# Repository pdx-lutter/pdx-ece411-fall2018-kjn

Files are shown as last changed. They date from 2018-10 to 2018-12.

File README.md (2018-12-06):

# Portland State University

## ECE 411 Practicum Project - Group 16

### Precision Temperature Control Unit

### Group Members

* Nathan Lutterman  
* Kimball Davis  
* Jason Houlihan  

### What is it?

Our group is designing and building a temperature control unit.  In a nutshell, the device reads some ambient temperature from a temperature sensor.  If the temperature being read is outside of some bound, above or blow, the device activates and utilizes a fan or a lamp (as a heater) respectively.

It's intended to be a small, portable temperature control unit.  The user interface consists of several 7-segment digital displays which are used as feedback for the user while inputting values for thresholds, as well as displaying the temperature being read.

### What's in it?

The device mostly charge is an AT89S52 8-bit microcontroller.  It'll be driving the 7-segment displays, reading the data from the temperature sensor, and triggering the relays for the fan and lamp.

---

### Important Documents

[Preliminary EAGLE PCB Design Schematic](docs/schematics/preliminary.sch)

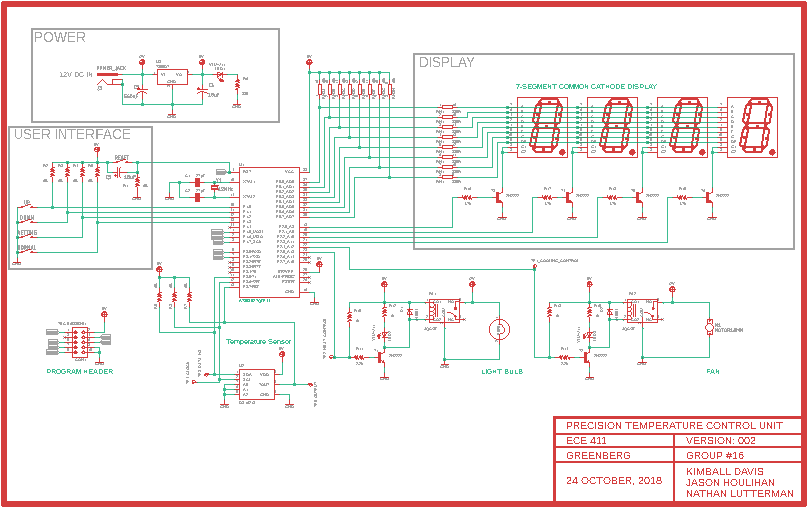
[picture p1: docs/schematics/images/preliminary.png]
Preliminary Schematic Thumbnail


### Licenses
SDCC suite is a collection of several components derived from different sources with different licenses.  

All project shared libraries used and provided by sdcc are under the GPL with the following exception:

>   As a special exception, if you link this library with other files,
>   some of which are compiled with SDCC, to produce an executable,
>   this library does not by itself cause the resulting executable to
>   be covered by the GNU General Public License. This exception does
>   not however invalidate any other reasons why the executable file
>   might be covered by the GNU General Public License.

The following is from the sdcc manual (found [here](http://sdcc.sourceforge.net/doc/sdccman.pdf)):

> – sdcc compiler:
> sdcc compiler is licensed under the GPLv2.
> The code or object files generated by SDCC suite are not licensed, so they can be used in FLOSS or
> proprietary (closed source) applications.
> 
> – dcpp preprocessor:
> derived from GCC cpp preprocessor http://gcc.gnu.org/; GPLv3 license
> 
> – sdas assemblers and sdld linker:
> derived from ASXXXX http://shop-pdp.kent.edu/ashtml/asxxxx.htm;
> license
> 
> – SDCC run-time libraries:
> The great majority of SDCC run-time libraries are licensed under the GPLv2+LE which allows linking
> of SDCC run-time libraries with proprietary (closed source) applications.
> Exception are pic device libraries and header files which are derived from Microchip header (.inc) and
> linker script (.lkr) files. Microchip requires that "The header files should state that they are only to
> be used with authentic Microchip devices" which makes them incompatible with the GPL. Pic device
> libraries and header files are located at non-free/lib and non-free/include directories respectively. SDCC
> should be run with the --use-non-free command line option in order to include non-free header files and
> libraries.
> 
> – sdbinutils utilities (sdar, sdranlib, sdnm, sdobjcopy):
> derived from GNU Binutils http://www.gnu.org/software/binutils/; GPLv3 license
> 
> – sdcclib librarian:
> GPLv2 license
> 
> – ucsim simulators:
> GPLv2 license
> 
> – sdcdb debugger:
> GPLv2 license
> 
> – gcc-test regression tests:
> derived from gcc-testsuite; no license explicitely specified, but since it is a part of GCC is probably
> GPLv3 licensed
> 
> – packihx:
> public domain
> 
> – makebin:
> zlib/libpng License
> 
> • libraries:
> – dbuf library:
> zlib/libpng License
> – Boost C++ libraries:
> http://www.boost.org/; Boost Software License 1.0 (BSL-1.0)
> Links to licenses:
> • GPLv2 license: http://www.gnu.org/licenses/old-licenses/gpl-2.0.html
> • LGPLv2.1 license: http://www.gnu.org/licenses/old-licenses/lgpl-2.1.html
> • GPLv3 license: http://www.gnu.org/licenses/gpl.html
> • zlib/libpng License: http://www.opensource.org/licenses/Zlib
> • Boost Software License 1.0 (BSL-1.0): http://www.opensource.org/licenses/BSL-1.0

The sdcc math.h and stdbool.h headers and libraries were used in the firmware of this project.

#### sdcc math.h License

   math.h: Floating point math function declarations

   Copyright (C) 2001, Jesus Calvino-Fraga, jesusc@ieee.org

   This library is free software; you can redistribute it and/or modify it
   under the terms of the GNU General Public License as published by the
   Free Software Foundation; either version 2, or (at your option) any
   later version.

   This library is distributed in the hope that it will be useful,
   but WITHOUT ANY WARRANTY; without even the implied warranty of
   MERCHANTABILITY or FITNESS FOR A PARTICULAR PURPOSE. See the
   GNU General Public License for more details.

   You should have received a copy of the GNU General Public License
   along with this library; see the file COPYING. If not, write to the
   Free Software Foundation, 51 Franklin Street, Fifth Floor, Boston,
   MA 02110-1301, USA.

   As a special exception, if you link this library with other files,
   some of which are compiled with SDCC, to produce an executable,
   this library does not by itself cause the resulting executable to
   be covered by the GNU General Public License. This exception does
   not however invalidate any other reasons why the executable file
   might be covered by the GNU General Public License.

#### sdcc stdbool.h

   stdbool.h - ANSI functions forward declarations

   Copyright (C) 2004, Maarten Brock, sourceforge.brock@dse.nl

   This library is free software; you can redistribute it and/or modify it
   under the terms of the GNU General Public License as published by the
   Free Software Foundation; either version 2, or (at your option) any
   later version.

   This library is distributed in the hope that it will be useful,
   but WITHOUT ANY WARRANTY; without even the implied warranty of
   MERCHANTABILITY or FITNESS FOR A PARTICULAR PURPOSE. See the
   GNU General Public License for more details.

   You should have received a copy of the GNU General Public License
   along with this library; see the file COPYING. If not, write to the
   Free Software Foundation, 51 Franklin Street, Fifth Floor, Boston,
   MA 02110-1301, USA.

   As a special exception, if you link this library with other files,
   some of which are compiled with SDCC, to produce an executable,
   this library does not by itself cause the resulting executable to
   be covered by the GNU General Public License. This exception does
   not however invalidate any other reasons why the executable file
   might be covered by the GNU General Public License.

#### 8051.h 

   8051.h: Register Declarations for the Intel 8051 Processor

   Copyright (C) 2000, Bela Torok / bela.torok@kssg.ch

   This library is free software; you can redistribute it and/or modify it
   under the terms of the GNU General Public License as published by the
   Free Software Foundation; either version 2, or (at your option) any
   later version.

   This library is distributed in the hope that it will be useful,
   but WITHOUT ANY WARRANTY; without even the implied warranty of
   MERCHANTABILITY or FITNESS FOR A PARTICULAR PURPOSE. See the
   GNU General Public License for more details.

   You should have received a copy of the GNU General Public License 
   along with this library; see the file COPYING. If not, write to the
   Free Software Foundation, 51 Franklin Street, Fifth Floor, Boston,
   MA 02110-1301, USA.

   As a special exception, if you link this library with other files,
   some of which are compiled with SDCC, to produce an executable,
   this library does not by itself cause the resulting executable to
   be covered by the GNU General Public License. This exception does
   not however invalidate any other reasons why the executable file
   might be covered by the GNU General Public License.

#### Circuit Schematic and PCB Layout Licensing

The work produced solely for this project, including the circuit diagram, PCB layout, and firmware is licensed under MIT.

Autodesk EAGLE was the CAD software used to produce both the circuit diagrams and the PCB layout design.

Autodesk EAGLE and other Autodesk trademarks may be found here: https://www.autodesk.com/company/legal-notices-trademarks/trademarks/autodesk-inc#top

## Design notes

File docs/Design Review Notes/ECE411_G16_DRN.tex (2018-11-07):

\documentclass[11pt]{article}

\usepackage[utf8]{inputenc} % Required for inputting international characters
\usepackage[T1]{fontenc} % Output font encoding for international characters

\usepackage{mathpazo} % Palatino font
\usepackage{graphicx}
\usepackage{geometry}
\usepackage{float}
\usepackage{amsmath}
\usepackage{tabu}
\usepackage{array}
\usepackage{cellspace}
\usepackage[table]{xcolor}
\usepackage{multirow}
\usepackage{multicol}
\usepackage{parskip}

\usepackage{titlesec}
\titlespacing\subsection{0pt}{1pt plus 4 pt minus 2pt}{1pt plus 4 pt minus 2pt}

\renewcommand{\baselinestretch}{1.25}
\geometry{margin=0.75 in}

\begin{document}

%----------------------------------------------------------------------------------------
%	TITLE PAGE
%----------------------------------------------------------------------------------------

\begin{titlepage} % Suppresses displaying the page number on the title page and the subsequent page counts as page 1
	\newcommand{\HRule}{\rule{\linewidth}{0.5mm}} % Defines a new command for horizontal lines, change thickness here
	
	\center % Centre everything on the page
	
	%------------------------------------------------
	%	Headings
	%------------------------------------------------
	
	\textsc{\LARGE Portland State University
}\\[.25cm] % Main heading such as the name of your university/college
	
	\textsc{\Large Department of Electrical and Computer Engineering }\\[.5cm] % Major heading such as course name
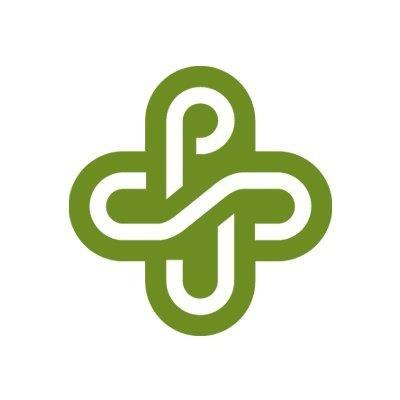
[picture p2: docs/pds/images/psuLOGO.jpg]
\\[.5cm]	
	\textsc{\LARGE ECE 411 - Industry Design Process }\\[0.75cm] % Minor heading such as course title
	
		\textsc{\Large Professor Andrew Greenberg, MS\\
Professor of Electrical \& Computer Engineering
 }\\[.75cm]
	
	%------------------------------------------------
	%	Title
	%------------------------------------------------
	
	\HRule\\[0.4cm]
	
	{\huge\bfseries Design Review Notes}\\[0.4cm] % Title of your document
	
	\HRule\\[1.5cm]
	
	%------------------------------------------------
	%	Author(s)
	%------------------------------------------------
	
%	\begin{minipage}{0.4\textwidth}
%		\begin{flushleft}
%			\large
%			\textit{By:}\\
%		 \textsc{Kimball S. Davis} % Your name
%		\end{flushleft}
%	\end{minipage}
%	~
%	\begin{minipage}{0.4\textwidth}
%		\begin{flushright}
%			\large
%			\textit{Professor of Electrical \& Computer Engineering}\\
%		 \textsc{Professor Branimir Pejcinovic, Ph.D.} % Supervisor's name
%		\end{flushright}
%	\end{minipage}
	
	% If you don't want a supervisor, uncomment the two lines below and comment the code above
	\Large{Group \#16:}\\
		 \Large\textsc{Kimball S. Davis, Jason Houlihan, \& Nathan Lutterman} % Your name
	
	%------------------------------------------------
	%	Date
	%------------------------------------------------
	
	\vfill\vfill\vfill\vfill % Position the date 3/4 down the remaining page
	
	{\large\today} % Date, change the \today to a set date if you want to be precise
	
	%------------------------------------------------
	%	Logo
	%------------------------------------------------
	
	%\vfill\vfill
	%\includegraphics[width=0.2\textwidth]{PSULOGO}\\[1cm] % Include a department/university logo - this will require the graphicx package
	 
	%----------------------------------------------------------------------------------------
	
	\vfill % Push the date up 1/4 of the remaining page
	
\end{titlepage}

%----------------------------------------------------------------------------------------
\setlength{\columnsep}{.2 in}

\setlength{\parskip}{0pt}

\section*{Schematic and Board Layout Design Review Notes}
\textbf{Team Being Reviewed:} Group 16: Kimball Davis, Jason Houlihan, Nathan Lutterman\\
\textbf{Reviewer:} Douglas Hall, Ph.D\\

\textit{NOTE: Although Professor Geenberg never directly reviewed our design, we discovered some flaws in our design while watching the reviews done in class. We included these in our review notes because we changed our design based on these observations before Dr. Hall reviewed the design.}

\section*{Schematic} 

\subsection*{Critical}

\begin{itemize}

    \item Missing bypass capacitors on +5V inputs to AT89S52. Added 100 nF bypass capacitors to design.
    \item Don't put anything on the NET layer that is not a net. We had some section labeling on the NET layer. The text was moved to the NOTES layer.
    
\end{itemize}

\subsection*{Major}

\begin{itemize}

    \item Not clear exactly what the power is coming from. Changed power supply labeling in schematic.
    \item Make sure there are adequate test points. Added test points for I2C signals for display.
    \item Not clear how much current the loads require to operate, or what the loads are. Labeled the loads on the schematic with part number, voltage, and current specifications.

\end{itemize}
		
\subsection*{Minor}

\begin{itemize}

    \item For LEDS use 500 to 1K resistors to keep them dimmer. Changed resistors in LED circuits from 330 to 1k $\Omega$
    \item When presenting a schematic for review be aware of the scale. If our schematic were projected on a screen or on a laptop with zoom capabilities it would be fine. Presented on 11x7 paper a lot of the text is hard to read.

\end{itemize}

\section*{Layout} 

\subsection*{Critical}

\begin{itemize}

    \item None
    
\end{itemize}

\subsection*{Major}

\begin{itemize}

    \item Will the voltage regulator need additional heat sinks based on the power the loads will draw?

\end{itemize}
		
\subsection*{Minor}

\begin{itemize}

    \item Consider printing top and bottom layers separately, or on transparencies that can overlap so it is easier for the reviewer to follow traces.
    \item Not clear what type of mounting hardware will be needed for connectors.

\end{itemize}

\section*{Bill of Materials} 

\begin{itemize}

    \item Power supply, fan, and light-bulb specifications are not clearly defined.
    
\end{itemize}

\end{document}

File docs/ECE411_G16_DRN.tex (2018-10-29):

\documentclass[11pt]{article}

\usepackage[utf8]{inputenc} % Required for inputting international characters
\usepackage[T1]{fontenc} % Output font encoding for international characters

\usepackage{mathpazo} % Palatino font
\usepackage{graphicx}
\usepackage{geometry}
\usepackage{float}
\usepackage{amsmath}
\usepackage{tabu}
\usepackage{array}
\usepackage{cellspace}
\usepackage[table]{xcolor}
\usepackage{multirow}
\usepackage{multicol}
\usepackage{parskip}

\usepackage{titlesec}
\titlespacing\subsection{0pt}{1pt plus 4 pt minus 2pt}{1pt plus 4 pt minus 2pt}

\renewcommand{\baselinestretch}{1.25}
\geometry{margin=0.75 in}

\begin{document}

%----------------------------------------------------------------------------------------
%	TITLE PAGE
%----------------------------------------------------------------------------------------

\begin{titlepage} % Suppresses displaying the page number on the title page and the subsequent page counts as page 1
	\newcommand{\HRule}{\rule{\linewidth}{0.5mm}} % Defines a new command for horizontal lines, change thickness here
	
	\center % Centre everything on the page
	
	%------------------------------------------------
	%	Headings
	%------------------------------------------------
	
	\textsc{\LARGE Portland State University
}\\[.25cm] % Main heading such as the name of your university/college
	
	\textsc{\Large Department of Electrical and Computer Engineering }\\[.5cm] % Major heading such as course name
\\[.5cm]
	\textsc{\LARGE ECE 411 - Industry Design Process }\\[0.75cm] % Minor heading such as course title
	
		\textsc{\Large Professor Andrew Greenberg, MS\\
Professor of Electrical \& Computer Engineering
 }\\[.75cm]
	
	%------------------------------------------------
	%	Title
	%------------------------------------------------
	
	\HRule\\[0.4cm]
	
	{\huge\bfseries Project Design Specification}\\[0.4cm] % Title of your document
	
	\HRule\\[1.5cm]
	
	%------------------------------------------------
	%	Author(s)
	%------------------------------------------------
	
%	\begin{minipage}{0.4\textwidth}
%		\begin{flushleft}
%			\large
%			\textit{By:}\\
%		 \textsc{Kimball S. Davis} % Your name
%		\end{flushleft}
%	\end{minipage}
%	~
%	\begin{minipage}{0.4\textwidth}
%		\begin{flushright}
%			\large
%			\textit{Professor of Electrical \& Computer Engineering}\\
%		 \textsc{Professor Branimir Pejcinovic, Ph.D.} % Supervisor's name
%		\end{flushright}
%	\end{minipage}
	
	% If you don't want a supervisor, uncomment the two lines below and comment the code above
	\Large{Group \#16:}\\
		 \Large\textsc{Kimball S. Davis, Jason Houlihan, \& Nathan Lutterman} % Your name
	
	%------------------------------------------------
	%	Date
	%------------------------------------------------
	
	\vfill\vfill\vfill\vfill % Position the date 3/4 down the remaining page
	
	{\large\today} % Date, change the \today to a set date if you want to be precise
	
	%------------------------------------------------
	%	Logo
	%------------------------------------------------
	
	%\vfill\vfill
	%\includegraphics[width=0.2\textwidth]{PSULOGO}\\[1cm] % Include a department/university logo - this will require the graphicx package
	 
	%----------------------------------------------------------------------------------------
	
	\vfill % Push the date up 1/4 of the remaining page
	
\end{titlepage}

%----------------------------------------------------------------------------------------
\setlength{\columnsep}{.2 in}

\setlength{\parskip}{0pt}

\section*{Executive Summary}
Everyday medical, industrial, and home applications need a precise temperature controller. Our digital temperature controller is primarily used to control the temperature of any device whose temperature keeps fluctuating and requires a constant watch. This system can be used in any organization where it is very important to maintain specific temperatures. This system is better than analogue/ thermostat systems, which have poor accuracy. Its main use is for temperature control of an incubator where maintaining a precise temperature is very important.\\

The digital temperature controller provides the temperature information on a LCD display, and when the temperature exceeds the set point, the load (heater) switches off. For the purpose of our practicum project, a lamp will be used as a load for demonstration purpose. If time permits we would also add a fan to cool the device when the temperature exceeds the set limit. Therefore the system keep switching the lamp, and fan, on and off which automatically controls the temperature of the system.\\

The digital temperature controller uses a microcontroller from the 8051 family (AT89S52), which is the bulk of the application. The display unit consists of four seven segment display pins which are interfaced to the microcontroller. The digital temperature sensor (DS1621) is interfaced to the microcontroller for sensing the temperature conditions. The system also provides four push buttons switches for adjusting, and setting the temperature. The microcontroller then polls the temperature information through a digital temperature sensor and displays the seven segment display units. When the corresponding temperature exceeds the set point, the lamp/fan automatically switches off/on.\\

The following are some examples of digital temperature controller using a microcontroller:
\begin{itemize}
    \item Outdoor use involving potential chemical contamination or electrical interference.
    \item Outdoor use involving potential chemical contamination or electrical interference.
    \item Medical equipment, amusement machines, vehicles, safety equipment, and installations subject to separate industry or government regulations.
    \item Systems, machines, and equipment that could present a risk to life or property.
    \item HVAC control for industrial and residential applications.
\end{itemize}

\pagebreak

\section*{Brief Market Analysis} 

While there are many uses for precision programmable temperature control units, home heating and cooling is a place where there is an available market, and a need for better more efficient thermostats. In a survey from the U.S. Energy Information Agency (EIA) it was found that while over 87$\%$of homes were equipped with HVAC, only roughly 52$\%$ of them had programmable thermostats. There is plenty of competition in the market from industry giants such as General Electric, Honeywell, and Emerson who currently have many similar products available some even offering entire smart home systems.\\

Where there is room for growth in the market is in ease of use, customization, and peripherals. A few things that would make our product stand out from the rest would be: LCD touchscreens, data logging for predictive thermostat control,and RFID implementation for personalized thermostat settings from room to room.\\

Ideally there would be several models with the same basic TCU as the engine. The price would depend on if it was the base model or the more advanced models with more functions/peripherals. Similar products on the market range from \$60 to \$100 for a basic programmable thermostat, and up to \$250 for the more advanced programmable models.

\section*{Requirements}
\subsection*{Must}
\begin{itemize}
    \item Accurately detect temperature 
    \item Accurately report temperature through a display
    \item Have a programmable temperature setting
    \item Switch between heating and cooling modes when temperature threshold is exceeded 
    \item Be easy to use
    \item Use an AT89S52 microcontroller
    \item Use > 25\% SMT components
    \item Have the processor on the PCB 
    \item Have in circuit Programming capabilities
    \item Use a two or more layer PCB, with solder mask and at least a top-side silk screen
    \item Area between 9-900 $cm^2$, and a linear dimension between 2-30 cm

\end{itemize}

\subsection*{Should}

\begin{itemize}

    \item Be as small as possible
    \item Have an enclosure

\end{itemize}
		
\subsection*{May}

\begin{itemize}

    \item Have data logging capabilities
    \item Have an LCD screen
    \item Include RFID programming

\end{itemize}

\section*{System Architecture}
The level 1 block diagram for our proposed design can be seen below.
	
	\begin{figure}[H]
	\centering
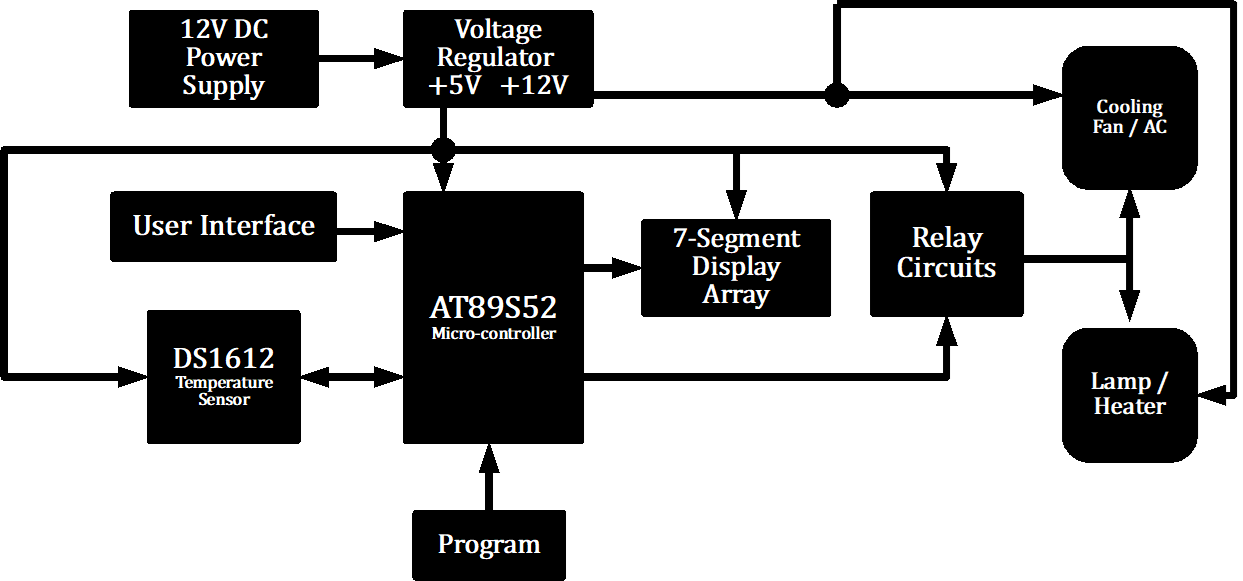
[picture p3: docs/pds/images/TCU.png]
	
		\caption{\textit{Block diagram of digital temperature controller.}}
	\end{figure}

\section*{Design Specifications}

\subsection*{Sensors}
\begin{itemize}
	\setlength\itemsep{-2px}
    \item Digital Temperature Sensor(DS1621)
    \item Push Buttons.

\end{itemize}

\subsection*{Actuators}
\begin{itemize}
	\setlength\itemsep{-2px}
    \item 7 Segment display pins
    \item Lamp and fan
    \item LEDs
\end{itemize}

\subsection*{Controller}
\begin{itemize}
	\setlength\itemsep{-2px}
    \item Microcontroller (AT89S52)
\end{itemize}

\subsection*{Additional}
\begin{itemize}
	\setlength\itemsep{-2px}
    \item Voltage regulator (LM7805C)
    \item Transistors (2N2222) 
    \item 5V Relays (JQC-3F)
    \item Resistors/Capacitors

\end{itemize}
	
\end{document}

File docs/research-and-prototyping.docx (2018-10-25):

Research and Prototyping

10/16/2018

I ordered the following USB ISP for programming the AT89S52. It is a requirement that we be able to program the MC in circuit and not on a daughter board. Read the specs in the link.

https://www.amazon.com/gp/product/B00AX4WQ00/ref=oh_aui_detailpage_o00_s00?ie=UTF8&psc=1

From the description they had the following layout for programming the MC for a different chip in a TQFP 32 pin out shown below.

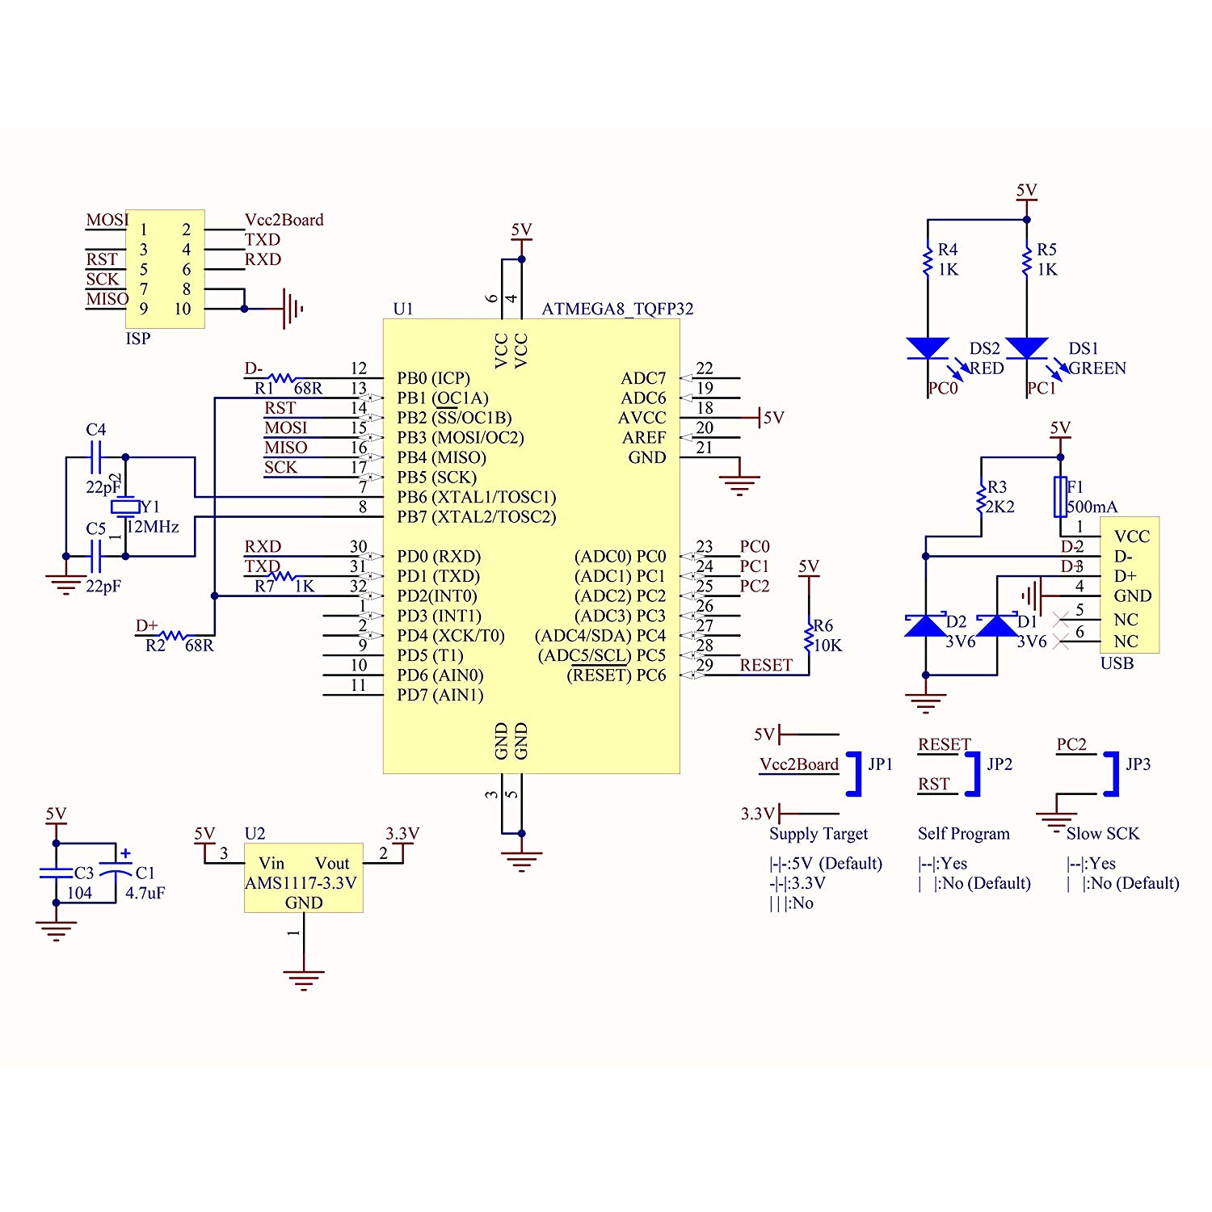
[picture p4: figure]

I translated the schematic for a basic pin out from the 10-pin connector for an AT89S52 in EAGLE shown below.

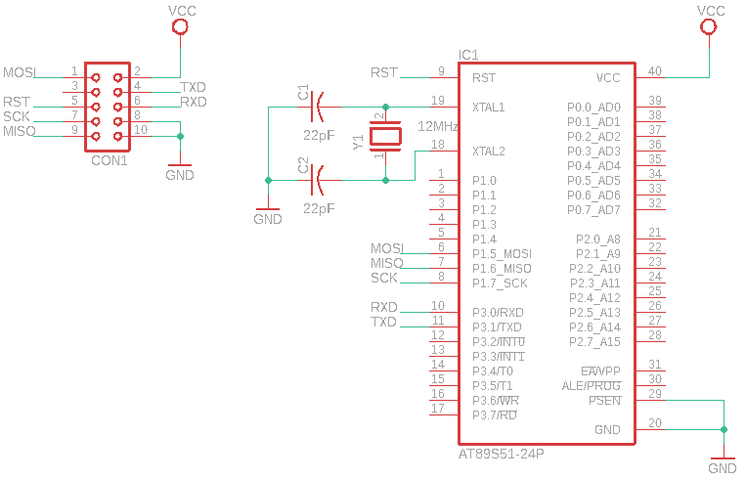
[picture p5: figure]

The only microcontroller I’ve ever used is the Beagle bone black from 371. I’ll need your feedback on what else this circuit needs or is missing for basic programming. I figure this is a good place to start, so we can get programming, and test functionality.

I’ve also requested free samples from ATMEL of AT89S52 in a DIL40 pin package. I have two coming that should be here in a week to a week and a half. We may want to order some that will get here faster.

The parts list from Jason’s link is below as well as a block diagram of the circuit.

- AT89S52 (8051 Microcontroller) – Buy AT89S52 Online (http://nevonexpress.com/AT89S52-8-Bit-Microcontroller-DIP-Mount-8051-Family.php)
- 7 Segment Display – Buy 7 Segment DIsplay Online (http://nevonexpress.com/7-Segment-Display-CA.php)
- DC Cooling Fan – Buy DC Fan Online (http://nevonexpress.com/12v-Brushless-DC-Cooling-Exhaust-Fan.php)
- LM35 Temperature Sensor – Buy LM35 Sensor Online (http://nevonexpress.com/LM35-Temperature-Sensor-For-Arduino-Ras-Pi-Microcontroller.php)
- Relay – Buy Relays Online (http://nevonexpress.com/Buy-Relays-Online.php)
- Relay Driver IC – Buy IC’s Online (https://nevonexpress.com/Buy-IC-and-Controllers-Online.php)
- Vtg Regulator IC – Buy IC’s Online (https://nevonexpress.com/Buy-IC-and-Controllers-Online.php)
- IC Socket – Buy IC Sockets Online (https://nevonexpress.com/Buy-IC-Sockets-Online.php)
- Resistors – Buy Resistors Online (https://nevonexpress.com/Buy-Resistors-Online.php)
- Capacitors – Buy Capacitors Online (https://nevonexpress.com/Buy-Capacitors-Online.php)
- Transistors – Buy Transistors Online (https://nevonexpress.com/Buy-Transistors-Online.php)
- Cables & Connectors – Buy Cables & Connectors Online (http://nevonexpress.com/Cables-&-Connectors.php)
- Diodes – Buy Diodes Online (https://nevonexpress.com/Buy-Diodes-Online.php)
- PCB – Buy PCB & Breadboards Online (https://nevonexpress.com/Buy-PCB-Breadboards-Online.php)
- LED’s – Buy LED Online (https://nevonexpress.com/Buy-LED-Displays-Online.php)
- Transformer/Adapter – Buy Transformers & Adapters Online (http://nevonexpress.com/Transformers.php)
- Push Button – Buy Buttons & Switches Online (https://nevonexpress.com/Buy-Electronics-Buttons-Switches-Online.php)
- Lamp

Software Specifications

- Keil µVision IDE
- MC Programming Language: Embedded C

Block Diagram

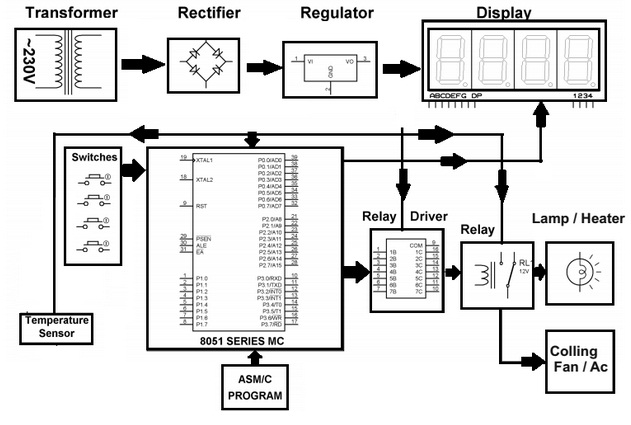
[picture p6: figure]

I think it will be a lot cheaper to order all of the parts individually, they want $105 for the kit which includes a pcb that we won’t need.

My thoughts on what we could do different for our project:

- Use a different/ more advanced temperature sensor
- Data logging
- 4 7-segment displays instead of 3
- We could have different loads to switch besides a dc fan and a light bulb
- We could build an actual enclosure to show proof of concept
- RFID tags that automatically set the temperature for a person when they walk into a room. (stolen from the lock box idea)

Some of these may be too much added work, I’ll need your feedback as to what you guys think is possible in the given amount of time.

Requirements/Specification Ideas:

- Parts list
  - Loads: Fan/lightbulb or Other
  - Temperature Sensor
  - RFID?
  - >25% SMT components
  - Correct 10-pin ribbon connector
- Temperature Range
- Sensitivity
- Power consumption
- Enclosure?
- Display
- Size
- Operation

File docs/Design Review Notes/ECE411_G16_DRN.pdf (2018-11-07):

### PORTLAND STATE UNIVERSITY

DEPARTMENT OF ELECTRICAL AND COMPUTER ENGINEERING


### ECE 411 - INDUSTRY DESIGN PROCESS

PROFESSOR ANDREW GREENBERG, MS PROFESSOR OF ELECTRICAL & COMPUTER ENGINEERING

# Design Review Notes

## Group #16:

KIMBALL S. DAVIS, JASON HOULIHAN, & NATHAN LUTTERMAN

November 7, 2018

### Schematic and Board Layout Design Review Notes

Team Being Reviewed: Group 16: Kimball Davis, Jason Houlihan, Nathan Lutterman
Reviewer: Douglas Hall, Ph.D

NOTE: Although Professor Geenberg never directly reviewed our design, we discovered some flaws in our design while watching the reviews done in class. We included these in our review notes because we changed our design based on these observations before Dr. Hall reviewed the design.

### Schematic

Critical
- Missing bypass capacitors on +5V inputs to AT89S52. Added 100 nF bypass capacitors to design.
- Don’t put anything on the NET layer that is not a net. We had some section labeling on the NET layer. The text was moved to the NOTES layer.
Major
- Not clear exactly what the power is coming from. Changed power supply labeling in schematic.
- Make sure there are adequate test points. Added test points for I2C signals for display.
- Not clear how much current the loads require to operate, or what the loads are. Labeled the loads on the schematic with part number, voltage, and current specifications.
Minor
- For LEDS use 500 to 1K resistors to keep them dimmer. Changed resistors in LED circuits from 330 to 1k Ω
- When presenting a schematic for review be aware of the scale. If our schematic were projected on a screen or on a laptop with zoom capabilities it would be fine. Presented on 11x7 paper a lot of the text is hard to read.

### Layout

Critical
- None
Major
- Will the voltage regulator need additional heat sinks based on the power the loads will draw? Minor
- Consider printing top and bottom layers separately, or on transparencies that can overlap so it is easier for the reviewer to follow traces.
- Not clear what type of mounting hardware will be needed for connectors.

### Bill of Materials

- Power supply, fan, and light-bulb specifications are not clearly defined.

1

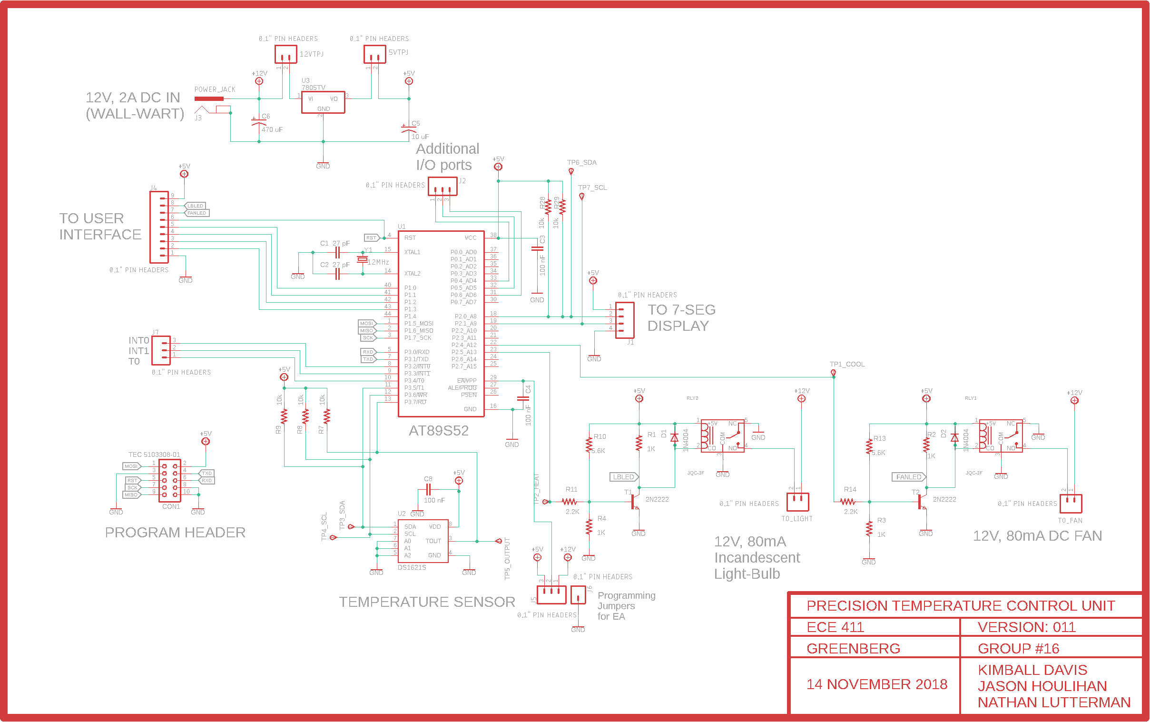
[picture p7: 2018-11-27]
docs/Schematics and Board designs/images/ECE411_G16_V11.png

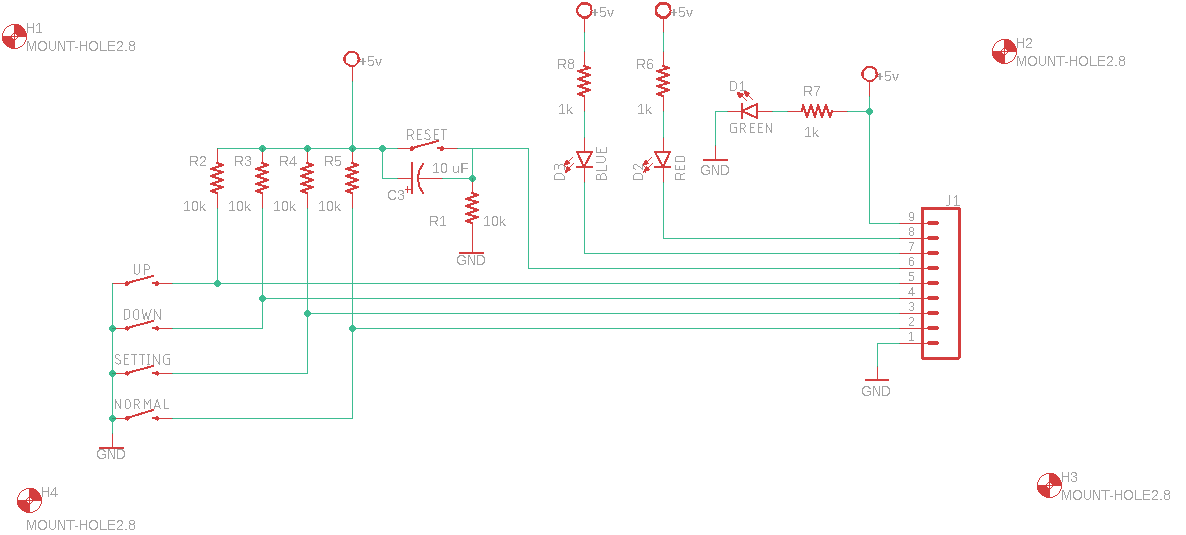
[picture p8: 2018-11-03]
docs/Schematics and Board designs/images/ECE411_G16_UIV1.png

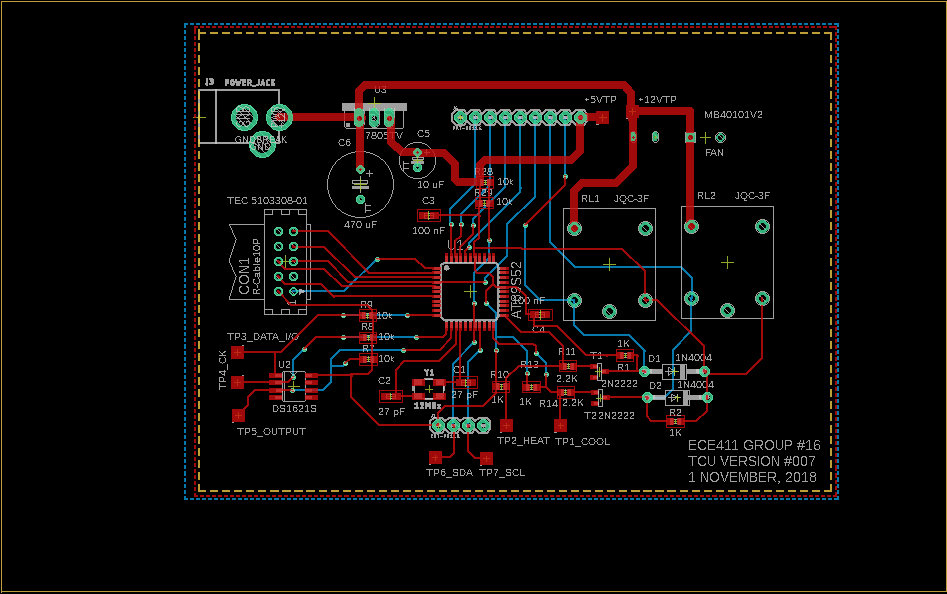
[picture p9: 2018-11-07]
docs/Schematics and Board designs/images/ECE411_G16_V7_BRD.png

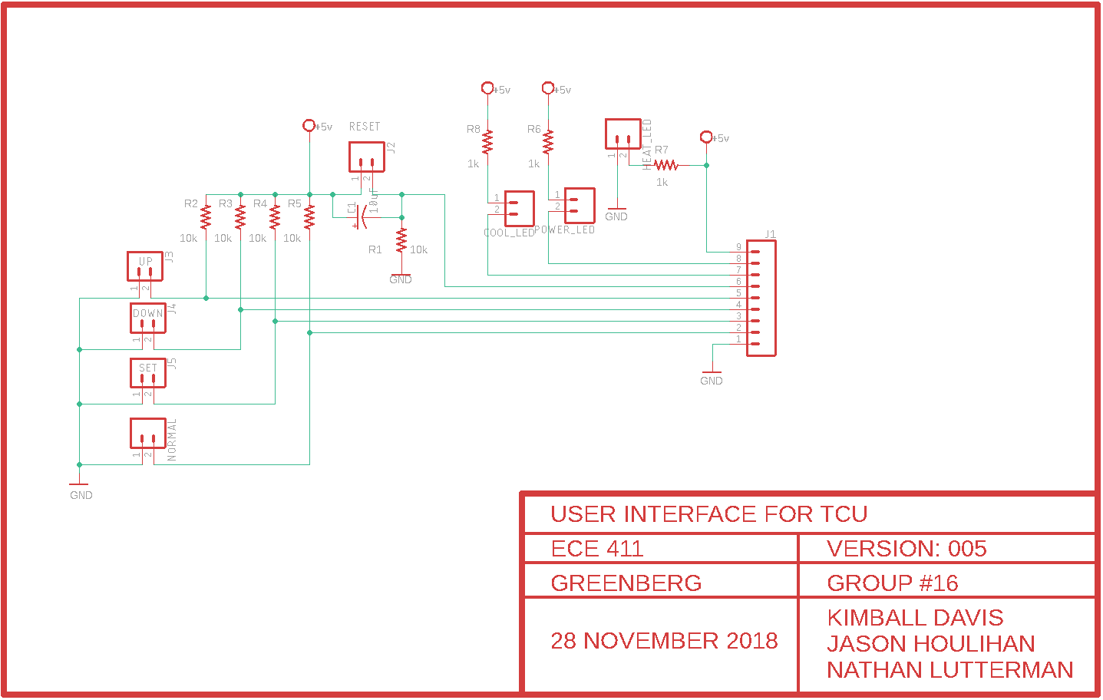
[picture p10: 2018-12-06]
docs/Schematics and Board designs/images/ECE411_G16_UIV5.png

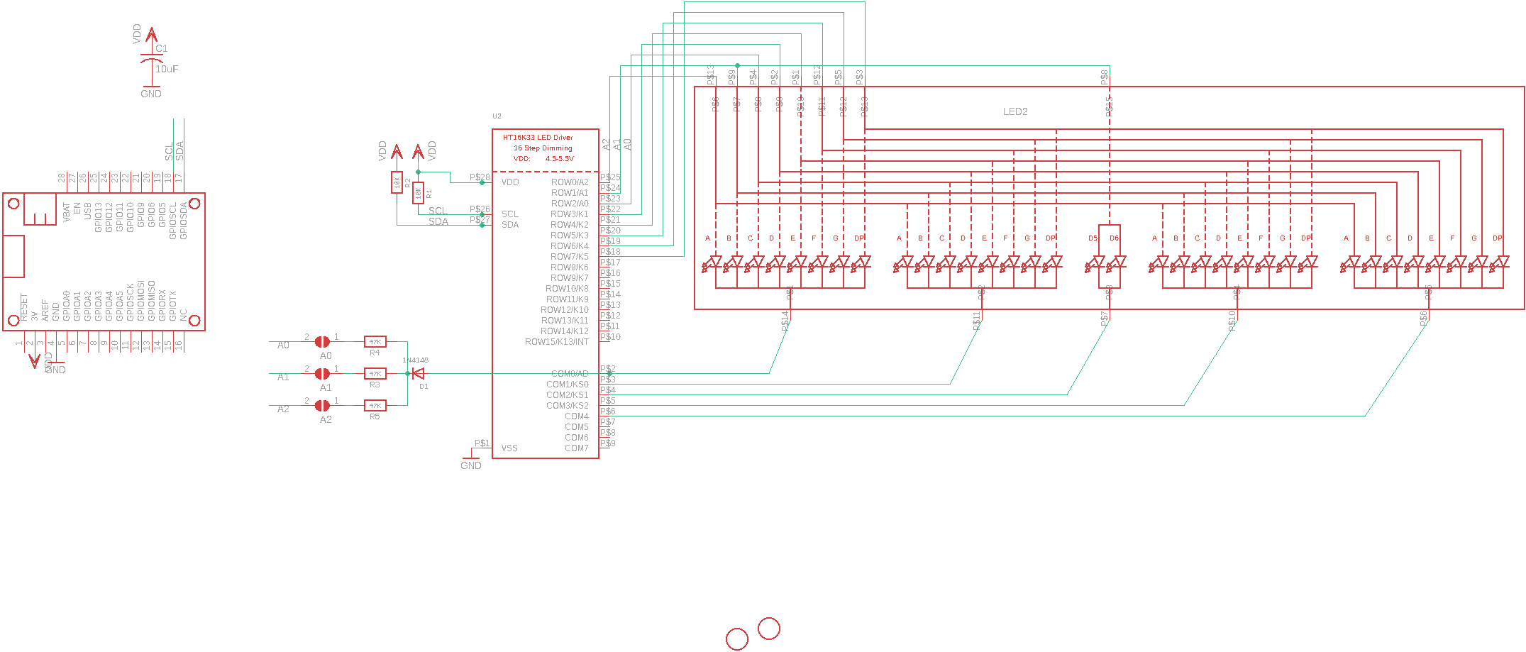
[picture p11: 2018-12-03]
docs/Schematics and Board designs/images/7seg_display_backpack.png

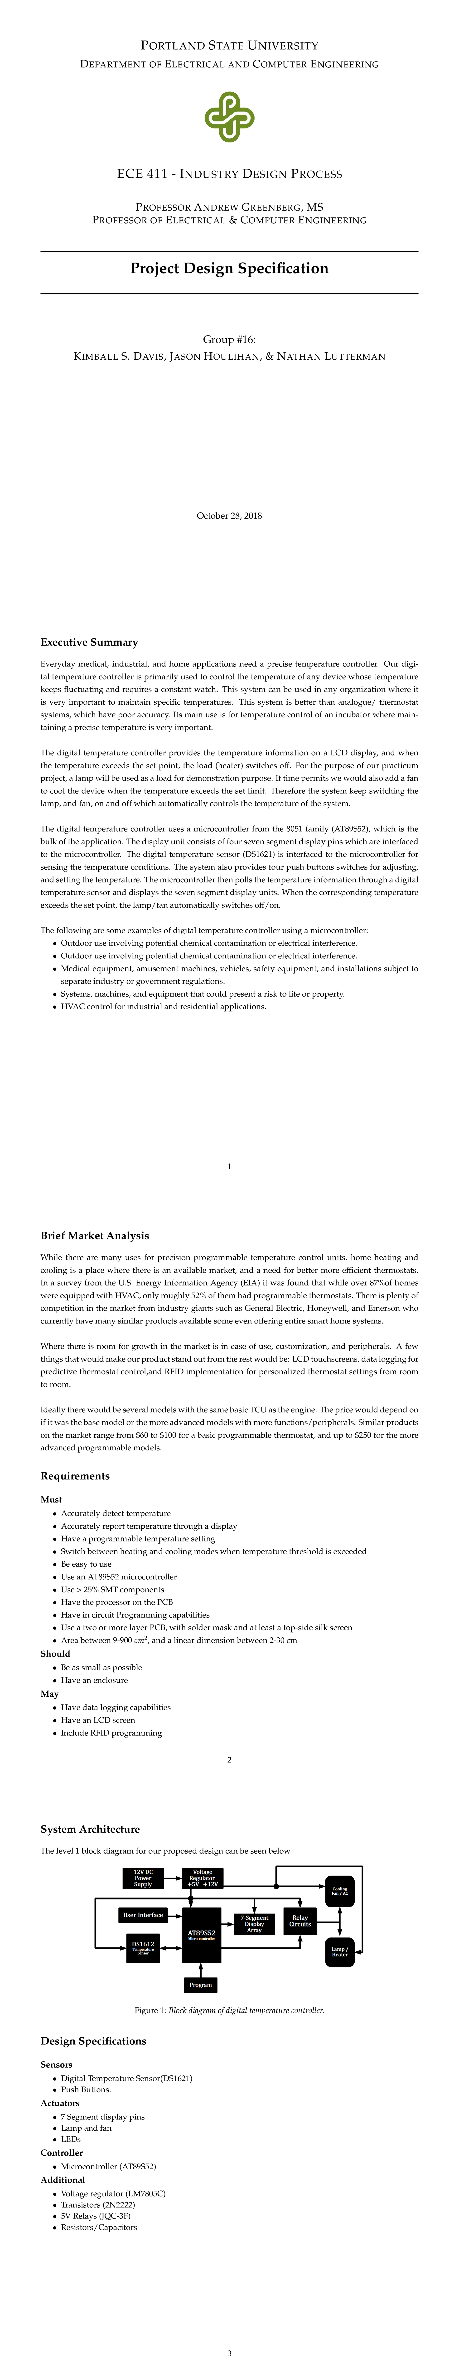
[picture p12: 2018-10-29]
docs/product-design-specification/pds.png

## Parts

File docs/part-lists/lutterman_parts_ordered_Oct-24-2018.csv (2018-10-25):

# | Quantity | Part Number | Manufacturer Part Number | Description | Customer Reference | Backorder | Unit Price | Extended Price
1 | 5 | AT89S52-24AU-ND | AT89S52-24AU | IC MCU 8BIT 8KB FLASH 44TQFP |  | 0 | 1.65000 | 8.25
2 | 3 | AT89S52-24PU-ND | AT89S52-24PU | IC MCU 8BIT 8KB FLASH 40DIP |  | 0 | 2.55000 | 7.65
3 | 3 | EG5530-ND | PR142C2000-136 | SWITCH PUSHBUTTON DPST 16A 125V |  | 0 | 2.19000 | 6.57
4 | 2 | P12346S-ND | ESE-20C343 | SWITCH PUSH SPST-NO 0.1A 14V |  | 0 | 1.37000 | 2.74
5 | 2 | CW181-ND | GPTS203211B | SWITCH PUSHBUTTON SPST 1A 30V |  | 0 | 0.74000 | 1.48
6 | 2 | 504PB-ND | 40-2385-01 | SWITCH PUSHBUTTON SPST 2A 14V |  | 0 | 1.52000 | 3.04
7 | 2 | CW180-ND | GPBS-850N | SWITCH PUSHBUTTON DPDT 0.3A 30V |  | 0 | 0.63000 | 1.26
8 | 3 | 563-1932-5-ND | TR1-01 | SWITCH PUSH SPST-NO 10MA 12V |  | 0 | 0.51000 | 1.53
9 | 1 | 1568-1856-ND | COM-14662 | KEYPAD - 12 BUTTON |  | 0 | 3.95000 | 3.95
10 | 10 | 450-1650-ND | 1825910-6 | SWITCH TACTILE SPST-NO 0.05A 24V |  | 0 | 0.10000 | 1.00
11 | 10 | 450-1804-ND | 1825910-7 | SWITCH TACTILE SPST-NO 0.05A 24V |  | 0 | 0.10600 | 1.06
12 | 1 | NHD-1.8-128160EF-CTXI#-FT-ND | NHD-1.8-128160EF-CTXI#-FT | DISPLAY LCD TFT TOUCH 24ZIF |  | 0 | 14.17000 | 14.17
13 | 1 | NHD-0108BZ-RN-YBW-33V-ND | NHD-0108BZ-RN-YBW-33V | LCD MOD CHAR 1X8 Y/G REFL STN |  | 0 | 7.55000 | 7.55
14 | 10 | 1830-1152-ND | INND-TS40RAB | 7-SEG. DISPLAY THROUGH HOLE |  | 0 | 0.89500 | 8.95
15 | 2 | 1568-1513-ND | PRT-12796 | JUMPER WIRE F/F 6" 20PCS |  | 0 | 1.95000 | 3.90
16 | 2 | 1568-1512-ND | PRT-12795 | JUMPER WIRE M/M 6" 20PCS |  | 0 | 1.95000 | 3.90
17 | 5 | CT2105MS-ND | 210-5MS | SWITCH SLIDE DIP SPST 100MA 20V |  | 0 | 0.62000 | 3.10

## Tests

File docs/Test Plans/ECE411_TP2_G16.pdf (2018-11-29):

Test Case Name: | TCU Unit Test #2 | Test ID#: | TCU-UT-02
Description: | Checks the function of the user interface circuitry. Verifies no opens/shorts and operation of LED's and switches. | Type: | Black Box
Name of Tester: | | Date:
Hardware Version: | User Interface - Version 005 | Time:
Setup: | 9-pin ribbon connector from user interface should be connected according to the pin assignments below. Pin 9: +5V Pin 8: Connect to normally open switch to ground Pin 7: Connect to normally open switch to ground Pin 6-2: Connect each pin to individual test point for volt meter Pin 1: Connect to ground
Step | Action | Expected Result | Pass | Fail | N/A | Comments
1 | Apply +5V to User Interface | Green power led should light up
2 | Measure voltage at pin 8. Depress normally open switch, measure voltage while switch is closed | Intitial voltage at pin 8 should measure 0V, when switch is closed voltage should measure +5V +/-5% Red LED (heat indicator) should be on
3 | Measure voltage at pin 7. Depress normally open switch, measure voltage while switch is closed | Initial voltage at pin 7 should measure 0V, when switch is closed voltage should measure +5V +/-5%, Blue LED (Cooling Indicator) should be on
4 | Measure voltage at pin 6. Depress Red switch (Reset) on user interface, measure voltage at pin 6 while switch is closed | The measured voltage at pin 6 should be +5V +/-5% with the switch open, and 0V with the switch closed
5 | Measure voltage at pin 5. Depress White switch (Up) on user interface, measure voltage at pin 5 while switch is closed | The measured voltage at pin 5 should be +5V +/-5% with the switch open, and 0V with the switch closed
6 | Measure voltage at pin 4. Depress Black switch (Down) on user interface, measure voltage at pin 4 while switch is closed | The measured voltage at pin 4 should be +5V +/-5% with the switch open, and 0V with the switch closed
7 | Measure voltage at pin 3. Depress Blue switch (Set) on user interface, measure voltage at pin 3 while switch is closed | The measured voltage at pin 3 should be +5V +/-5% with the switch open, and 0V with the switch closed
8 | Measure voltage at pin 2. Depress Green switch (Normal) on user interface, measure voltage at pin 2 while switch is closed | The measured voltage at pin 2 should be +5V +/-5% with the switch open, and 0V with the switch closed

Overall Test Results:

Test Writer: Kimball S. Davis

Tester Information

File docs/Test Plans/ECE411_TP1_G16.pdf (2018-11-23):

Test Case Name: | TCU Unit Test #1 | Test ID#: | TCU-UT-01
Description: | Checks the power supply output. Confirms when device is plugged in that voltage regulator supplies approximately +5V and +12V to the circuit. | Type: | Black Box
Name of Tester: | | Date:
Hardware Version: | Temperature Control Unit - Version 01 | Time:
Setup: | Test point jumpers 12VTPJ, and 5VTPJ should be removed. The 12V wall wart should be connected to the TCU module through power jack J3, and plugged in to a 120V 60 Hz power outlet.
Step | Action | Expected Result | Pass | Fail | N/A | Comments
1 | Measure voltage at 12VTPJ pin 1 with oscilloscope | The measured voltage should be 12 V +/-5% with a ripple voltage of < 120 mV.
2 | Measure voltage at Light Jumper pin 1 with oscilloscope | The measured voltage should be 12 V +/-5% with a ripple voltage of < 120 mV.
3 | Measure voltage at Fan Jumper pin 1 with oscilloscope | The measured voltage should be 12 V +/-5% with a ripple voltage of < 120 mV.
4 | Measure voltage at Programming Jumpers pin 1 with oscilloscope | The measured voltage should be 12 V +/-5% with a ripple voltage of < 120 mV.
5 | Connect jumper 12VTPJ to supply voltage to 7805 regulator | Voltage at 12VTPJ pin 1 should remain 12 V +/- 5% with a ripple voltage of < 120 mV
6 | Measure Voltage at 5VTPJ pin 1 with oscilloscope | The measured voltage should be 5 V +/-5% with a ripple voltage of < 50 mV.
7 | Connect jumper 5VTPJ to supply voltage to TCU circuit | Voltage at 5VTPJ pin 1 should remain 5 V +/- 5% with a ripple voltage of < 50 mV
8 | Measure voltage at Pin 38 of AT89S52 with oscilloscope | The measured voltage should be 5 V +/-5% with a ripple voltage of < 50 mV.
9 | Measure voltage at pin 8 of DS1621 with oscilloscope | The measured voltage should be 5 V +/-5% with a ripple voltage of < 50 mV.

Overall Test Results:

Test Writer: Kimball S. Davis

Tester Information

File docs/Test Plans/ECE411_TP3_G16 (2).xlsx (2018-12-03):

Test Writer: Nathan Lutterman
Test Case Name: |  | TCU Unit Test #2 |  |  |  | Test ID#: | TCU-UT-02
Description: |  | Checks that the input of the AT89S52 on pins (i.e. the output of the DS1621S temperature sensor) is reflected correctly in output pins 18 and 19 of the AT89S52 |  |  |  | Type: | Black Box
Tester Information
Name of Tester: |  |  |  |  |  | Date:
Hardware Version: |  | Temperature Control Unit - Version 11 |  |  |  | Time:
Setup: |  | Test point jumpers 12VTPJ, and 5VTPJ should be applied. The 12V wall wart should be connected to the TCU module through power jack J3, and plugged in to a 120V 60 Hz power outlet. The TCU should be placed in a space with a known ambient temperature. The tests will assume 21ºC. Using test firmware version `0.2.0`, flash the TCU using an ISP plugged in to header CON1 using a 10-pin IDC cable. The firmware will configure the temperature sensor to set the TH (temperature high) register to 100ºC and the TL (temperature low) register to 0ºC. To note, the THF and TLF (temp high flag and temp low flag) bits should not be asserted in the status register when read. The temperature sensor will run in continuous mode, the values being read will be in half-Centigrade measurements. The uC will continuously send “read temperature” (0xAA) commands to the temperature sensor, which will respond with the temperature in 2 bytes. These values will be written to pin 11 (P3.5) on the AT89S52 from pin 1 (SDA) on the DS1612. Wait at least 1 second for system set up and configuration. After 1 second, begin examining the test points with a mixed signal oscilloscope.
Step | Action | Expected Result | Pass | Fail | N/A | Comments
1 | Measure signal at TP4_SCL | Periodic clock signal at ~100kHz
2 | Measure signal at TP3_SDA
3 | Measure signal at TP7_SCL | Periodic clock signal at ~100kHz
4 | Measure signal at TP6_SDA
Overall Test Results:

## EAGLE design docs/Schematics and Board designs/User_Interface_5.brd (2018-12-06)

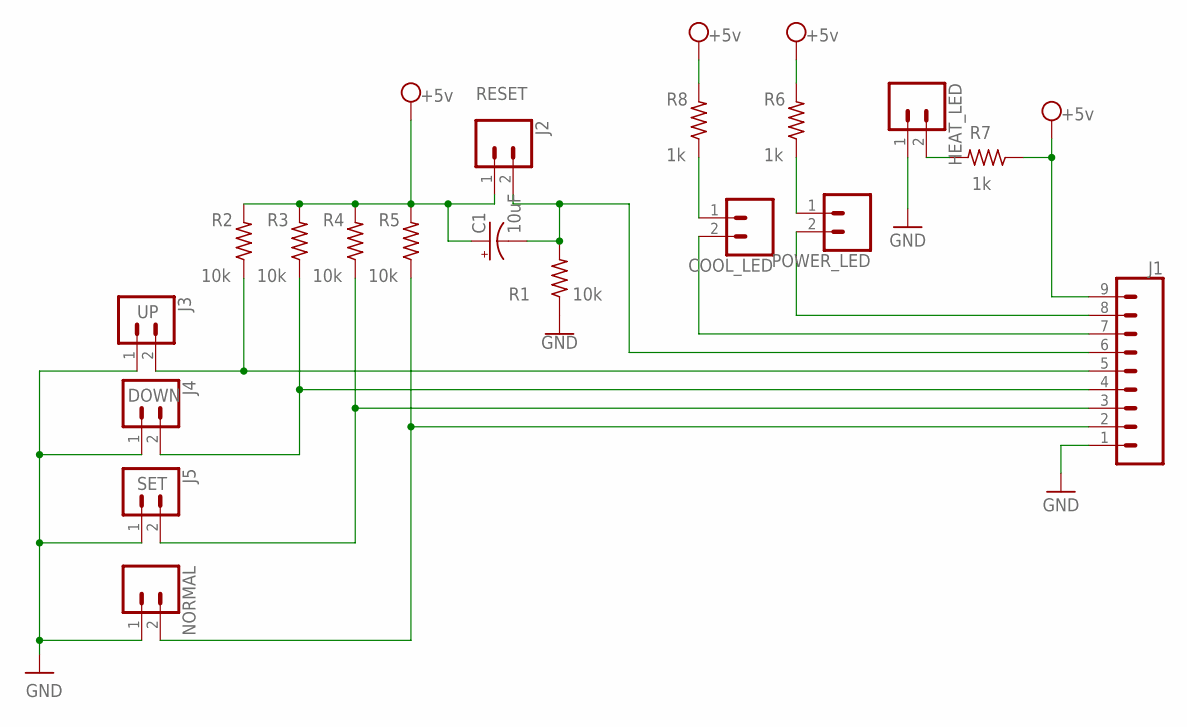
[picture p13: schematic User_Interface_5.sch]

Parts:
C1: 10uF; CPOL-RADIAL-2.5MM-5MM
COOL_LED: CONN_02; 1X02
HEAT_LED: CONN_02; 1X02
J1: CONN_09; 1X09
J2: RESET; 1X02
J3: UP; 1X02
J4: DOWN; 1X02
J5: SET; 1X02
NORMAL: CONN_02; 1X02
POWER_LED: CONN_02; 1X02
R1, R2, R3, R4, R5: 10k; R0603
R6, R7, R8: 1k; R0603

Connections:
GND: HEAT_LED.1, J1.1, J3.1, J4.1, J5.1, NORMAL.1, R1.1
unnamed: COOL_LED.1, R8.1
unnamed: J1.8, POWER_LED.2
unnamed: COOL_LED.2, J1.7
unnamed: J1.5, J3.2, R2.1
unnamed: J1.4, J4.2, R3.1
unnamed: J1.3, J5.2, R4.1
unnamed: J1.2, NORMAL.2, R5.1
unnamed: POWER_LED.1, R6.1
unnamed: HEAT_LED.2, R7.2
RST: C1.2 (-), J1.6, J2.2, R1.2
VCC: C1.1 (+), J1.9, J2.1, R2.2, R3.2, R4.2, R5.2, R6.2, R7.1, R8.2

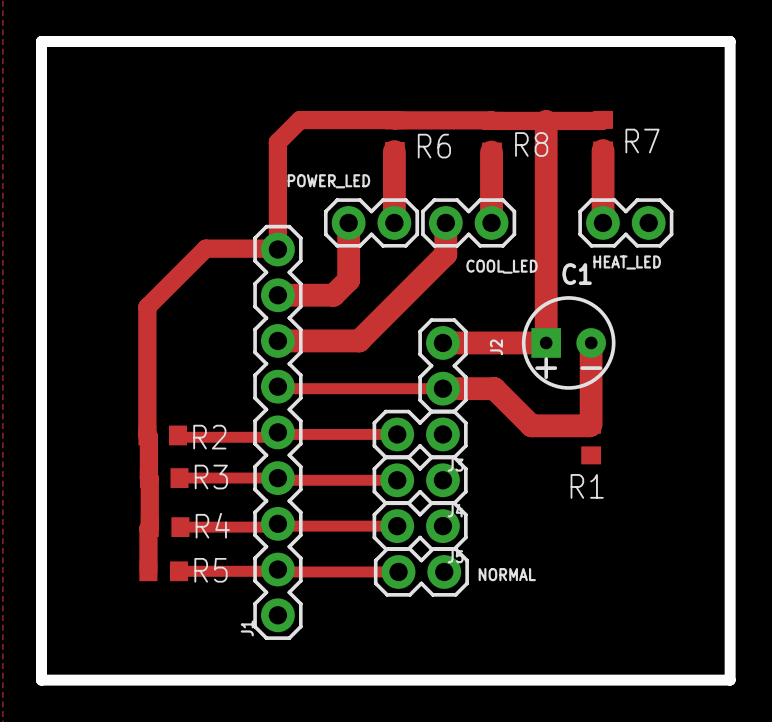
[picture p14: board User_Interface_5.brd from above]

Board: 2 copper layers, 38.3 x 35.5 mm, 18 parts (0 on the bottom side), 12 nets.

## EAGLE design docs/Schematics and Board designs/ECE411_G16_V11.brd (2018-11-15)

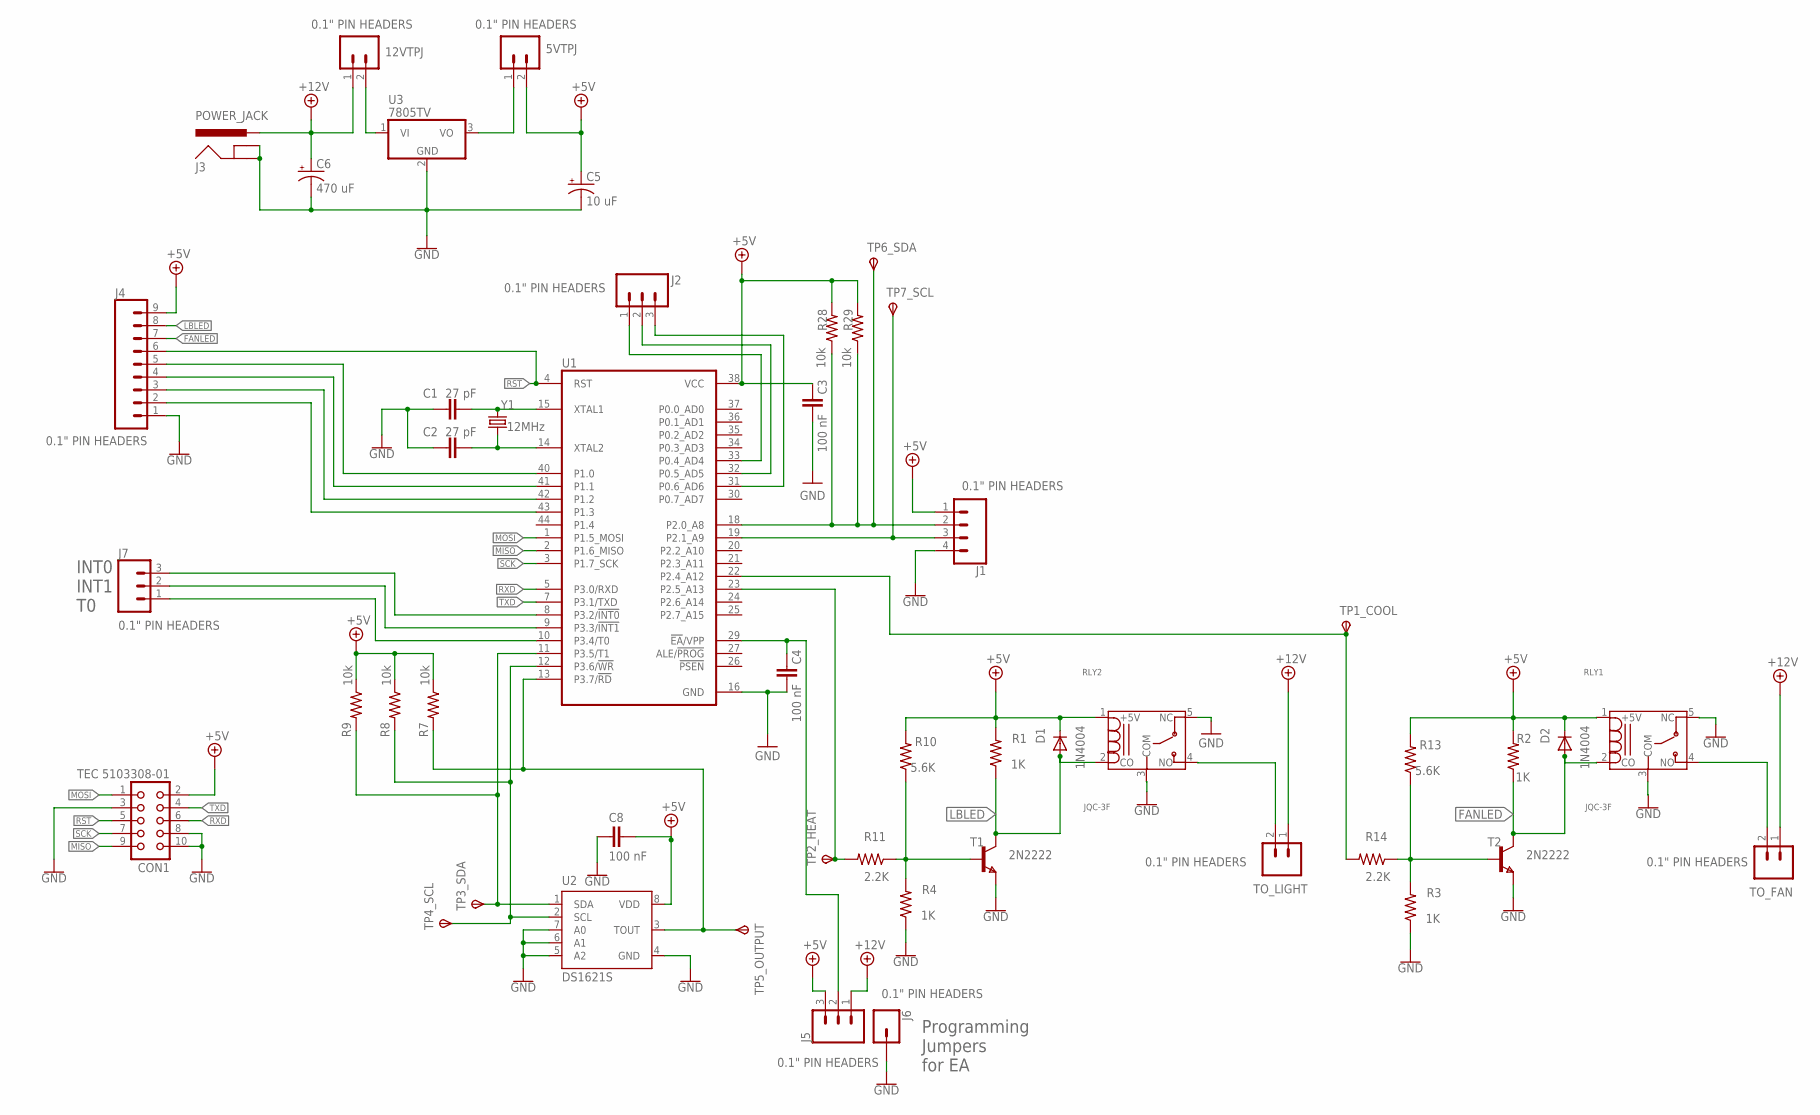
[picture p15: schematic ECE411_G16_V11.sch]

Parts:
5VTPJ, 12VTPJ: 0.1" PIN HEADERS; 1X02
C1, C2: 27 pF; RESC0603_M
C3, C4, C8: 100 nF; RESC0603_M
C5: 10 uF; TT2D6
C6: 470 uF; TT5D11
CON1: TEC 5103308-01; CON10
D1, D2: 1N4004; DO41-10
J1: 0.1" PIN HEADERS; 1X04
J2, J5, J7: 0.1" PIN HEADERS; 1X03
J3: POWER_JACK; POWER_JACK_PTH
J4: 0.1" PIN HEADERS; 1X09
J6: 0.1" PIN HEADERS; 1X01
R1, R2, R3, R4: 1K; R0603
R7, R8, R9, R28, R29: 10k; R0603
R10, R13: 5.6K; R0603
R11, R14: 2.2K; R0603
RLY1, RLY2: JQC-3F; T073
T1, T2: 2N2222; SOT-23
TO_FAN: 0.1" PIN HEADERS; 1X02
TO_LIGHT: 0.1" PIN HEADERS; 1X02
TP1_COOL, TP2_HEAT, TP3_SDA, TP4_SCL, TP5_OUTPUT, TP6_SDA, TP7_SCL: TPSTP20SQ; TP20SQ
U1: AT89S52; TQFP44
U2: DS1621S; SO08
U3: 7805TV; TO220V
Y1: 12MHz; CRYSTAL-SMD-5X3.2-4PAD

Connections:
+5V: 5VTPJ.2, C3.2, C5.+, C8.2, CON1.2, D1.C, D2.C, J1.1, J4.9, J5.3, R1.2, R2.2, R7.1, R8.1, R9.1, R10.2, R13.2, R28.2, R29.2, RLY1.1 (+5V), RLY2.1 (+5V), U1.38 (VCC), U2.8 (VDD)
+12V: 12VTPJ.1, C6.+, J3.PWR, J5.1, TO_FAN.1, TO_LIGHT.1
FANLED: D2.A, J4.7, R2.1, RLY1.2 (CO), T2.1 (C)
GND: C1.1, C2.1, C3.1, C4.1, C5.-, C6.-, C8.1, CON1.3, CON1.8, CON1.10, J1.4, J3.GND, J3.GNDBREAK, J4.1, J6.1, R3.1, R4.1, RLY1.3 (COM), RLY1.5 (NC), RLY2.3 (COM), RLY2.5 (NC), T1.2 (E), T2.2 (E), U1.16 (GND), U1.17 (GND), U2.4 (GND), U2.5 (A2), U2.6 (A1), U2.7 (A0), U3.2 (GND)
LBLED: D1.A, J4.8, R1.1, RLY2.2 (CO), T1.1 (C)
MISO: CON1.9, U1.2 (P1.6_MISO)
MOSI: CON1.1, U1.1 (P1.5_MOSI)
unnamed: C1.2, U1.15 (XTAL1), Y1.1
unnamed: C2.2, U1.14 (XTAL2), Y1.3 (2)
unnamed: J1.2, R28.1, R29.1, TP6_SDA.TP, U1.18 (P2.0_A8)
unnamed: J1.3, TP7_SCL.TP, U1.19 (P2.1_A9)
unnamed: 12VTPJ.2, U3.1 (VI)
unnamed: 5VTPJ.1, U3.3 (VO)
unnamed: RLY2.4 (NO), TO_LIGHT.2
unnamed: C4.2, J5.2, U1.29 (!EA!/VPP)
unnamed: R7.2, TP5_OUTPUT.TP, U1.13 (P3.7/!RD), U2.3 (TOUT)
unnamed: R8.2, TP4_SCL.TP, U1.12 (P3.6/!WR), U2.2 (SCL)
unnamed: R9.2, TP3_SDA.TP, U1.11 (P3.5/T1), U2.1 (SDA)
unnamed: R11.2, TP2_HEAT.TP, U1.23 (P2.5_A13)
unnamed: R4.2, R10.1, R11.1, T1.3 (B)
unnamed: J2.1, U1.33 (P0.4_AD4)
unnamed: J2.2, U1.32 (P0.5_AD5)
unnamed: R14.2, TP1_COOL.TP, U1.22 (P2.4_A12)
unnamed: R3.2, R13.1, R14.1, T2.3 (B)
unnamed: J2.3, U1.31 (P0.6_AD6)
unnamed: RLY1.4 (NO), TO_FAN.2
unnamed: J7.3, U1.8 (P3.2/!INT0)
unnamed: J7.2, U1.9 (P3.3/!INT1)
unnamed: J7.1, U1.10 (P3.4/T0)
unnamed: J4.5, U1.40 (P1.0)
unnamed: J4.4, U1.41 (P1.1)
unnamed: J4.3, U1.42 (P1.2)
unnamed: J4.2, U1.43 (P1.3)
RST: CON1.5, J4.6, U1.4 (RST)
RXD: CON1.6, U1.5 (P3.0/RXD)
SCK: CON1.7, U1.3 (P1.7_SCK)
TXD: CON1.4, U1.7 (P3.1/TXD)

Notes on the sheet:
Programming Jumpers for EA
INT0 INT1 T0

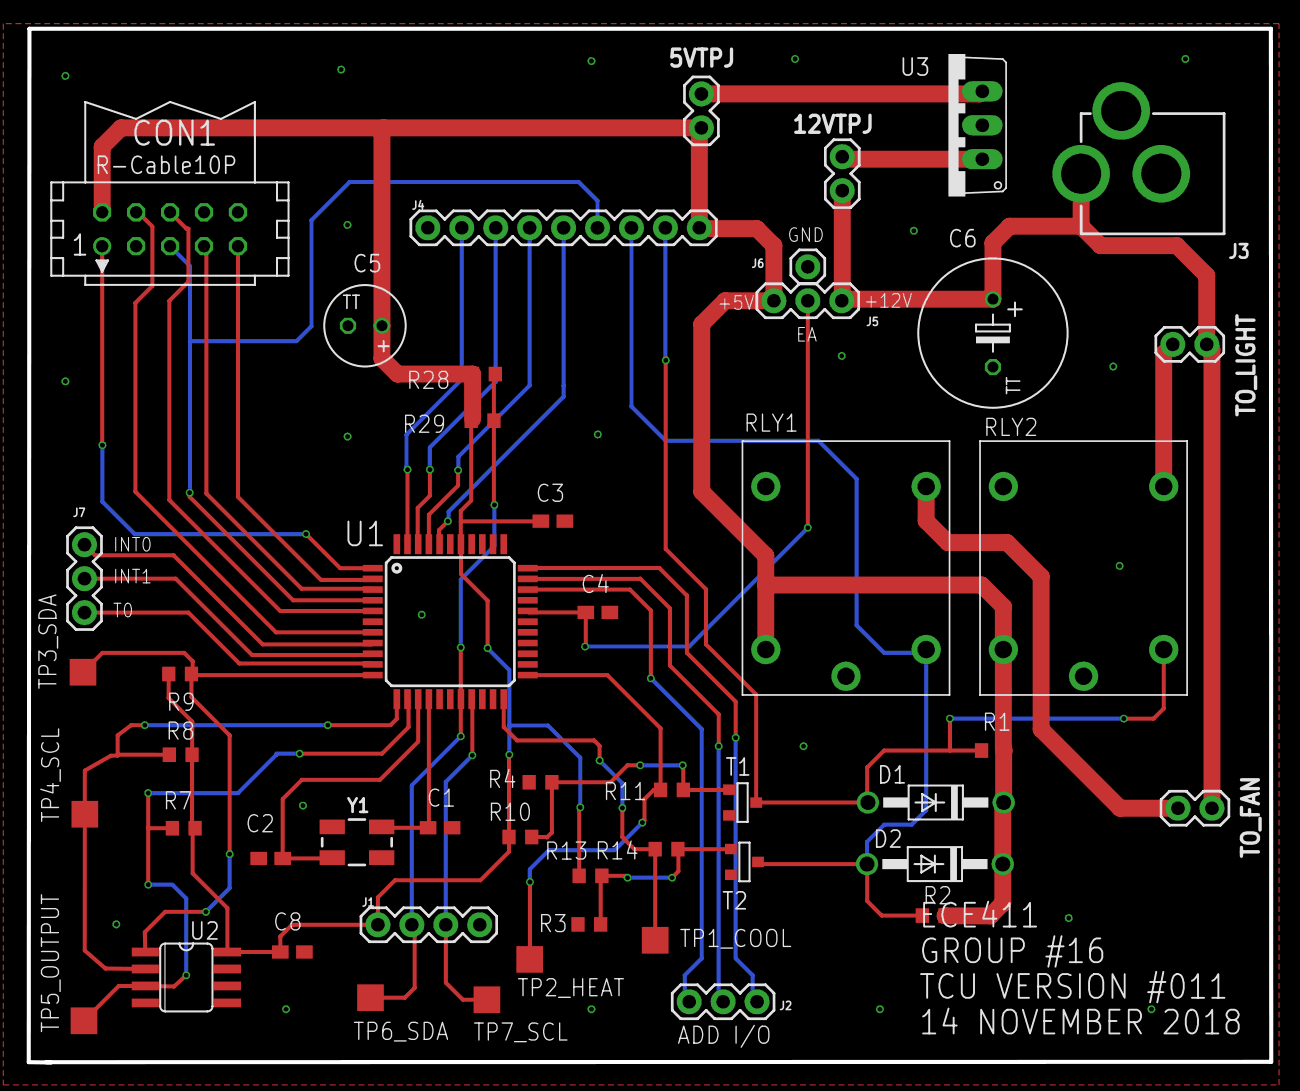
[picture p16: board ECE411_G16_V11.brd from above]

Board: 2 copper layers, 93.0 x 77.4 mm, 49 parts (0 on the bottom side), 37 nets.

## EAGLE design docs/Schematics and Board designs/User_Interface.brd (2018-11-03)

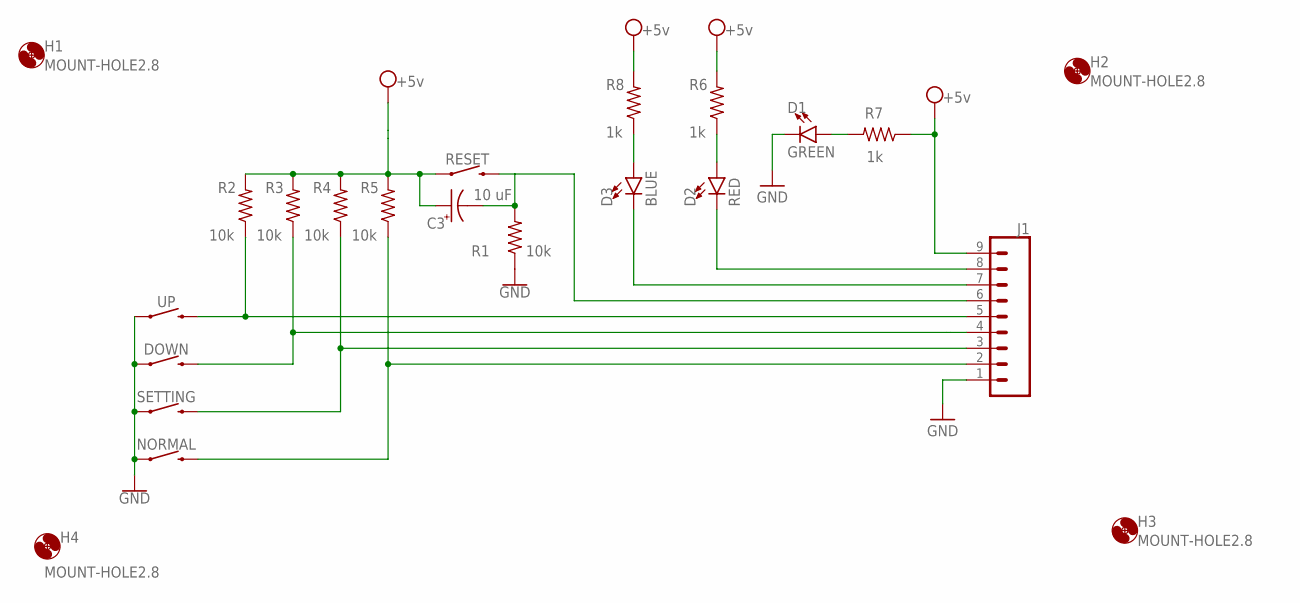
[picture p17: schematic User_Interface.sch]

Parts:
C3: 10 uF; TT2D6
D1: GREEN; LED-1206
D2: RED; LED-1206
D3: BLUE; LED-1206
DOWN: MOMENTARY-SWITCH-SPST-PTH-6.0MM; TACTILE_SWITCH_PTH_6.0MM
H1, H2, H3, H4: MOUNT-HOLE2.8; 2,8
J1: CONN_09; 1X09
NORMAL: MOMENTARY-SWITCH-SPST-PTH-6.0MM; TACTILE_SWITCH_PTH_6.0MM
R1, R2, R3, R4, R5: 10k; R0603
R6, R7, R8: 1k; R0603
RESET: MOMENTARY-SWITCH-SPST-PTH-6.0MM; TACTILE_SWITCH_PTH_6.0MM
SETTING: MOMENTARY-SWITCH-SPST-PTH-6.0MM; TACTILE_SWITCH_PTH_6.0MM
UP: MOMENTARY-SWITCH-SPST-PTH-6.0MM; TACTILE_SWITCH_PTH_6.0MM

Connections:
GND: D1.C, DOWN.1, J1.1, NORMAL.1, R1.1, SETTING.1, UP.1
unnamed: D1.A, R7.2
unnamed: D2.C, J1.8
unnamed: D3.C, J1.7
unnamed: J1.5, R2.1, UP.3 (2)
unnamed: DOWN.3 (2), J1.4, R3.1
unnamed: J1.3, R4.1, SETTING.3 (2)
unnamed: J1.2, NORMAL.3 (2), R5.1
unnamed: D2.A, R6.1
unnamed: D3.A, R8.1
RST: C3.-, J1.6, R1.2, RESET.3 (2)
VCC: C3.+, J1.9, R2.2, R3.2, R4.2, R5.2, R6.2, R7.1, R8.2, RESET.1

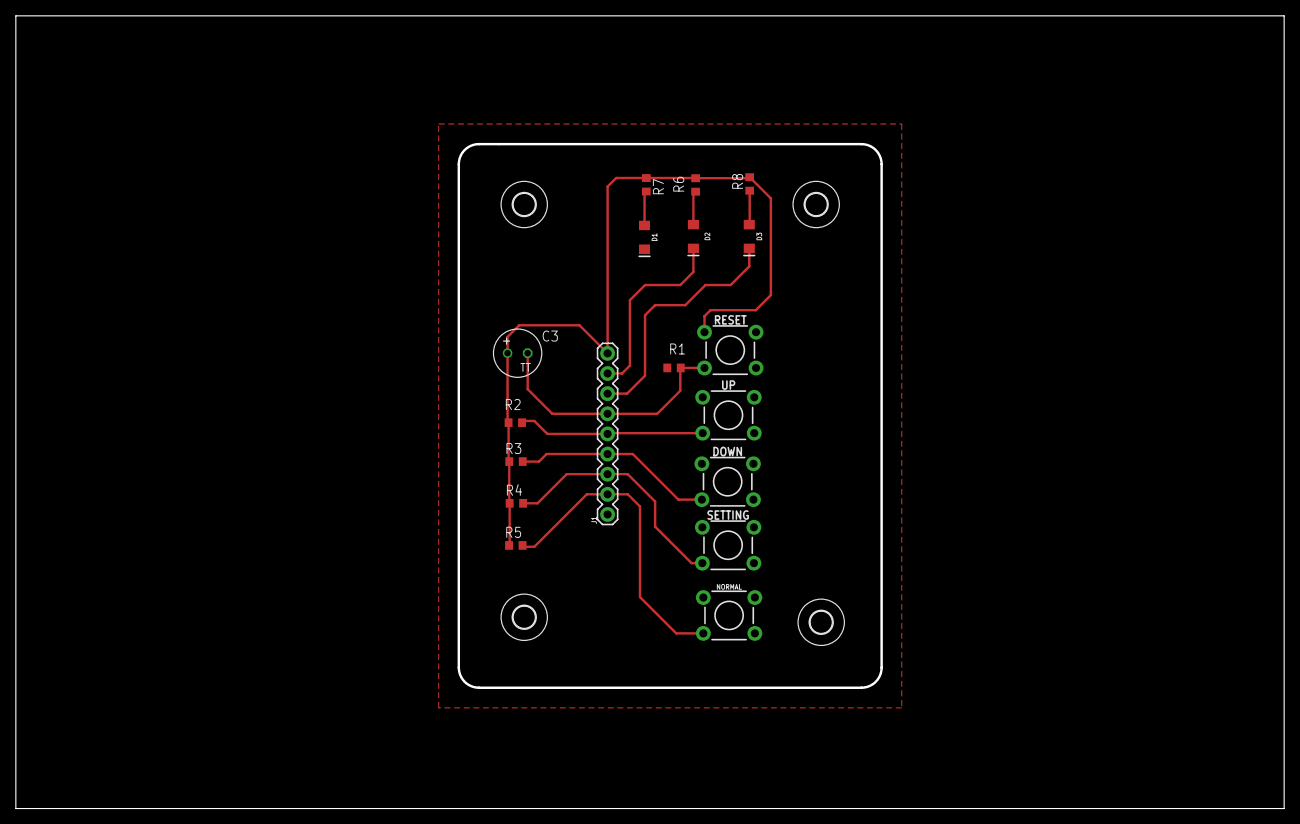
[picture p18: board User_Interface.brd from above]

Board: 2 copper layers, 160.0 x 100.0 mm, 22 parts (0 on the bottom side), 12 nets.

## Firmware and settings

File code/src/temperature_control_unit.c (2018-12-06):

#include <8051.h>
#include <stdbool.h>
#include <math.h>

#include "temperature_control_unit.h"

/**
 *
 * TODO List
 * TODO:  Double check if we need to wait for ACK when sending bytes
 */

unsigned char number_table[] = {
	0x3F, /* 0 */
	0x06, /* 1 */
	0x5B, /* 2 */
	0x4F, /* 3 */
	0x66, /* 4 */
	0x6D, /* 5 */
	0x7D, /* 6 */
	0x07, /* 7 */
	0x7F, /* 8 */
	0x6F, /* 9 */
	0x77, /* a */
	0x7C, /* b */
	0x39, /* C */
	0x5E, /* d */
	0x79, /* E */
	0x71, /* F */
};

#define DISPLAY_BUFFER_SIZE 10
unsigned char display_buffer[] = {
	0x00, /* unsigned char 1 and period spot */
	0x00, /* not used */
	0x00, /* unsigned character 2 and period */
	0x00, /* not used */
	0x00, /* colon (0xFF for colon on, 0x00 for colon off) */
	0x00, /* not used */
	0x00, /* unsigned char 3 and period */
	0x00, /* not used */
	0x00, /* unsigned char 4 and period */
	0x00  /* not used */
};

//|   0   |  0   |   0  |   0   |
//| Green | Blue | Black| White |
//| BACK  | SET  | DOWN | UP    |
unsigned char currently_pressed_buttons = 0x0;

//|   0   |  0   |   0  |   0   |
//| Green | Blue | Black| White |
//| BACK  | SET  | DOWN | UP    |
unsigned char debounced_buttons = 0x0;

unsigned char display_brightness = FULL_BRIGHTNESS; //Defaults to FULL THROTTLE

// Available user modes:
//
// MODE_DISPLAY_TEMPERATURE     0x00;
// MODE_CONFIGURE_TEMP_HIGH     0x01;
// MODE_CONFIGURE_TEMP_LOW      0x02;
// MODE_CONFIGURE_TEMP_UNIT     0x03;
// MODE_CONFIGURE_TEMP_ROUNDING 0x04;
// MODE_CONFIGURE_BRIGHTNESS    0x05;
unsigned char current_user_mode = MODE_DISPLAY_TEMPERATURE; 

int user_setting_temp_high_threshold = 40; //Degress celsius
int user_setting_temp_low_threshold  = 0; //Degress celsius

// This method assumes a 12MHz oscillator
// Most operations on the 8051 take 1/12 oscillator periods, so we'll use that as a basis for the delay
// All arithmetic instructions execute in 1us (except increment data pointer)
// However, since we're realistically working with numbers outside of the range of the 8-bit BCD format
// there *are definitely* going to be more clock cycles used (possibly up to 10x or more) when waiting
// for operations on values greater than 256
// Check the assembly output of the keil (assumed) compiler if exact numbers of operations are needed
void delay(unsigned long min_clock_cycles_to_wait)
{
	int i;
	for(i = 0;i < min_clock_cycles_to_wait; i++);
}

// Idea taken from: https://stackoverflow.com/questions/44308679/8051-i2c-bitbang
// It's basically just a small delay to ensure that the clock rate is 
// no faster than 1/5th of the uC clock rate (500kHz/5 = 100kH, with a 12MHz oscillator)
// Addition is a single clock cycle operation on the 8051
// The HT16K33 controller has a maximum min-set-up time of 1.3us and the DS16 4.7us, so we need at least 5us
// (realistically, this whole operation will take slightly longer than 5us)
void i2c_delay(void)
{
	unsigned int i = 0;
	for (i = 0; i < 5; i++);
}

void i2c_sda_write(unsigned char sfr_address, unsigned char value)
{
	switch (sfr_address)
	{
		case DISPLAY_SFR: P2_0 = value; break;
		case TEMP_SENSOR_SFR: P3_5 = value; break;
		default:break;
	}
}

unsigned char i2c_sda_read(unsigned char sfr_address)
{
	unsigned char result = 0;
	switch (sfr_address)
	{
		case DISPLAY_SFR: result = (unsigned char) P2_0; break;
		case TEMP_SENSOR_SFR: result = (unsigned char) P3_5; break;
		default:break;
	}
	return result;
}

void i2c_scl_write(unsigned char sfr_address, unsigned char value)
{
	switch (sfr_address)
	{
		case DISPLAY_SFR: P2_1 = value; break;
		case TEMP_SENSOR_SFR: P3_6 = value; break;
		default:break;
	}
	i2c_delay();
}

void i2c_start(unsigned char sfr_address)
{
	i2c_scl_write(sfr_address, 0);
	i2c_sda_write(sfr_address, 1);
	i2c_scl_write(sfr_address, 1);
	i2c_sda_write(sfr_address, 0);
	i2c_scl_write(sfr_address, 0);
}
 
void i2c_stop(unsigned char sfr_address)
{
	i2c_scl_write(sfr_address, 0);
	i2c_sda_write(sfr_address, 0);
	i2c_scl_write(sfr_address, 1);
	i2c_sda_write(sfr_address, 1);
}
 
unsigned char i2c_send_byte(unsigned char sfr_address, unsigned char data_out)
{
	unsigned char i, ack_bit;
	for (i = 0; i < 8; i++) {
		i2c_scl_write(sfr_address, 0);
		if ((data_out & 0x80) == 0) {
			i2c_sda_write(sfr_address, 0);
		} else {
			i2c_sda_write(sfr_address, 1);
		}
		i2c_scl_write(sfr_address, 1);
		data_out<<=1;
	}
	i2c_scl_write(sfr_address, 0);
	i2c_sda_write(sfr_address, 1);
	i2c_scl_write(sfr_address, 1);
	ack_bit = i2c_sda_read(sfr_address);
	i2c_scl_write(sfr_address, 0);

	return ack_bit;
}
 
unsigned char i2c_read_byte(unsigned char sfr_address)
{
	unsigned char i, received = 0;
	for (i = 0; i < 8; i++) {
		i2c_scl_write(sfr_address, 1);
		if(i2c_sda_read(sfr_address))
			received |= 1;
		if(i < 7)
			received <<= 1;
		i2c_scl_write(sfr_address, 0);
	}
	return received;
}

// Reads the 2-byte values from the temperature sensor
// We can achieve greater than 0.5 degree C resolution by truncating the LSB
// from the read value and then reading COUNT_REMAIN value using the
// Read Counter command.
// The Read Slopw command should then be issued to obtain the COUNT_PER_C
// value.  The higher resolution temp can be calculated by:
//
// TEMP = TEMP_READ - 0.25 + (COUNT_PER_C - COUNT_REMAIN) / COUNT_PER_C
float read_temp_sensor(void)
{
	unsigned char address_byte = 0x91;

	unsigned long millisecond = 1000;

	//TO NOTE, from the sdcc manual:
	//> SDCC supports (single precision 4 bytes) floating point numbers; the format is somewhat similar to IEEE, but
	//> it is not IEEE; in particular, denormalized floating -point numbers are not supported. The floating point support
	//> routines are derived from gcc’s floatlib.c
	float temperature;

	//Slope and count_remaining are going to be implicitly cast into floats from unsigned char
	float slope;
	float count_remaining;

	write_temp_sensor_command(START_TEMP_SENSOR_CONVERSION);
	i2c_stop(TEMP_SENSOR_SFR);

	//Temperature conversion time is almost a full second_byte (750ms) and may take up to a full second_byte
	delay(1000*millisecond);//multiplication... this wait  maaay be (read: probably will be) longer than 1000ms

	write_temp_sensor_command(READ_TEMPERATURE);
	
	// A second_byte start signal is required for reading after sending the write command
	i2c_start(TEMP_SENSOR_SFR);
	i2c_send_byte(TEMP_SENSOR_SFR, address_byte);
	temperature = i2c_read_byte(TEMP_SENSOR_SFR);
	//Since we're going to perform the calculation for higher precision (same accuracy)
	//we basically just throw this second byte away (even then it's still only the first bit we care about)
	i2c_read_byte(TEMP_SENSOR_SFR);
	i2c_stop(TEMP_SENSOR_SFR);

	write_temp_sensor_command(READ_COUNT_REMAIN);
	i2c_start(TEMP_SENSOR_SFR);
	i2c_send_byte(TEMP_SENSOR_SFR, address_byte);
	count_remaining = i2c_read_byte(TEMP_SENSOR_SFR);
	i2c_stop(TEMP_SENSOR_SFR);
	
	write_temp_sensor_command(READ_SLOPE);
	i2c_start(TEMP_SENSOR_SFR);
	i2c_send_byte(TEMP_SENSOR_SFR, address_byte);
	slope = i2c_read_byte(TEMP_SENSOR_SFR);
	i2c_stop(TEMP_SENSOR_SFR);

	//More notes about this conversion available here:
	// https://casper.berkeley.edu/svn/trunk/roach/sw/linux/Documentation/hwmon/ds1621
	temperature = (float) (temperature - (0.25 + (slope - count_remaining) / slope));
	
//	if (second & 0x80) //MSB is set if it's fractional
//	{
//		if (temperature < 0)
//			temperature -= 0.50;
//		else
//			temperature += 0.50;
//	}
	
	return temperature;
}

void clear_display_buffer(void)
{
	int i;
	for (i = 0; i < DISPLAY_BUFFER_SIZE; i++)
	{
		display_buffer[i] = 0x00;
	}
}

void write_to_display(void)
{
	unsigned char address = 0x70 << 1; 
	unsigned char write_bit = 0x00; //LSB is 0 when writing over i2c (or twi)
	unsigned char address_with_write = address | write_bit;

	unsigned char i;

	i2c_start(DISPLAY_SFR);
	i2c_send_byte(DISPLAY_SFR, address_with_write);
	/*
		A byte write operation requires a START condition,
		slave address with R/W bit, a valid Command code /
		Register address, a Data and a STOP condition.
	*/
	/*
		When an address is provided, the address is stored and incremented
		by the lcd controller on its own
	*/
	i2c_send_byte(DISPLAY_SFR, 0x00); //0x00 is the starting address of the 7-set disp
	for (i=0; i<DISPLAY_BUFFER_SIZE; i++) {
		i2c_send_byte(DISPLAY_SFR, display_buffer[i]);
	}
	i2c_stop(DISPLAY_SFR);
}

//Writes a single byte to send a command to the display
void write_display_command(unsigned char command_byte)
{
	// The address is shifted left once because the address is only 7 bits,
	// followed by a read/write bit.
	// So in actuality, with the read/write bit being appended, it's value is
	// 0xE0 or 0xE1 for write/read respectively.
	// but the ACTUAL i2c address is 0x70
	unsigned char address = 0x70 << 1; 
	unsigned char write_bit = 0x00; //LSB is 0 when writing over i2c (or twi)
	unsigned char address_with_write = address | write_bit;

	i2c_start(DISPLAY_SFR);
	i2c_send_byte(DISPLAY_SFR, address_with_write);
	/*
		A byte write operation requires a START condition,
		slave address with R/W bit, a valid Command code /
		Register address, a Data and a STOP condition.
	*/
	i2c_send_byte(DISPLAY_SFR, command_byte);
	i2c_stop(DISPLAY_SFR);
}

void write_temp_sensor_config(unsigned char config)
{
	write_temp_sensor_command(ACCESS_TEMP_SENSOR_CONFIG);
	i2c_send_byte(TEMP_SENSOR_SFR, config);
	i2c_stop(TEMP_SENSOR_SFR);
}

//Writes a single byte to send a command to the temp sensor
void write_temp_sensor_command(unsigned char command_byte)
{
/*
	Writing to the E^2 requires a maximum of 10ms at room temperature. 
	After issuing a write command, no further writes should 
	be requested for at least 10ms.*
 */
	unsigned char control_byte = 0x90;
	unsigned char write_bit = 0x00; 
	// Keeping this for now just to show that the write bit (LSB) is 0
	// on purpose (will remove later)
	unsigned char address_with_write = control_byte | write_bit;
	/*
	The DS1621 I2C address is 000 (since there are no other temp sensors).
	These three bits (000) are the LEAST significant bits of the slave
	(the temp sensor) address.  They're 000 since all of the address lines
	are tied to ground.

	A control byte is the first byte received following the start 
	condition from the MASTER (the AT89S52)

	A control byte is a 4-bit control code (1001 for the DS1621) and 3 bits 
	for the address (A2, A1, A0), with the last bit being a 1 for a read 
	and 0 for a write:

		1001 0001  <-- Read operation from device 000
		1001 0000  <-- Write operation to device 000

	After receiving 1001 000x, the slave device outputs an ACK 
	signal on the SDA line
	*/

	i2c_start(TEMP_SENSOR_SFR);
	i2c_send_byte(TEMP_SENSOR_SFR, address_with_write);
	i2c_send_byte(TEMP_SENSOR_SFR, command_byte);
}

void update_displayed_temperature(float temperature)
{
	unsigned char first_digit, second_digit, third_digit, fourth_digit;
	float temp_fraction_part, temp_integer_part= 0.0;

	clear_display_buffer();

	temp_fraction_part = modff(temperature, &temp_integer_part);
	temp_fraction_part *= 100;

	if (temperature >= 100) //I sure hope not
	{
		first_digit  = number_table[1];
		second_digit = number_table[(int)temp_integer_part % 10];
		third_digit  = number_table[(int)temp_integer_part % 10] | PERIOD_CHARACTER;
		fourth_digit = number_table[(int)temp_fraction_part/ 10];
	} 
	else if (temperature < 0) 
	{
		// Fractional part should always be positive for display
		temp_fraction_part*= -1;
		first_digit = HYPHEN_CHARACTER;
		if (temperature <= -10)
		{
			second_digit = number_table[(int)temp_integer_part / 10];
			third_digit  = number_table[(int)temp_integer_part % 10] | PERIOD_CHARACTER;
			fourth_digit = number_table[(int)temp_fraction_part / 10];
		} else
		{ 
			second_digit = number_table[(int)temp_integer_part % 10] | PERIOD_CHARACTER;
			third_digit  = number_table[(int)temp_fraction_part / 10];
			fourth_digit = number_table[(int)temp_fraction_part % 10];
		}
	}
	else
	{
		first_digit  = number_table[(int)temp_integer_part / 10];
		second_digit = number_table[(int)temp_integer_part % 10] | PERIOD_CHARACTER;
		third_digit  = number_table[(int)temp_fraction_part / 10];
		fourth_digit = number_table[(int)temp_fraction_part % 10];
	}

		display_buffer[DISPLAY_FIRST_DIGIT]  = first_digit;
		display_buffer[DISPLAY_SECOND_DIGIT] = second_digit;
		display_buffer[DISPLAY_THIRD_DIGIT]  = third_digit;
		display_buffer[DISPLAY_FOURTH_DIGIT] = fourth_digit;
}

void updated_displayed_setting_selection(unsigned char selected_setting_mode)
{
	clear_display_buffer();

	switch(selected_setting_mode)
	{
	case MODE_CONFIGURE_TEMP_HIGH:
		display_buffer[DISPLAY_FIRST_DIGIT]  = LETTER_H;
		display_buffer[DISPLAY_SECOND_DIGIT] = LETTER_I;
		break;
	case MODE_CONFIGURE_TEMP_LOW:
		display_buffer[DISPLAY_FIRST_DIGIT]  = LETTER_L;
		display_buffer[DISPLAY_SECOND_DIGIT] = LETTER_O;
		break;
	case MODE_CONFIGURE_TEMP_UNIT:
		display_buffer[DISPLAY_FIRST_DIGIT]  = LETTER_U;
		display_buffer[DISPLAY_SECOND_DIGIT] = LETTER_n;
		break;
	case MODE_CONFIGURE_TEMP_ROUNDING:
		display_buffer[DISPLAY_FIRST_DIGIT]  = LETTER_r;
		display_buffer[DISPLAY_SECOND_DIGIT] = LETTER_n;
		display_buffer[DISPLAY_THIRD_DIGIT]  = LETTER_d;
		break;
	case MODE_CONFIGURE_BRIGHTNESS:
		display_buffer[DISPLAY_FIRST_DIGIT]  = LETTER_b;
		display_buffer[DISPLAY_SECOND_DIGIT] = LETTER_r;
		break;
	default: return;
	}
}

void read_buttons(void)
{
	unsigned char white = BUTTON_WHITE;
	unsigned char black = BUTTON_BLACK;
	unsigned char blue  = BUTTON_BLUE;
	unsigned char green = BUTTON_GREEN;
	
	currently_pressed_buttons |= BUTTON_UP&((!white)<<0);
	currently_pressed_buttons |= BUTTON_DOWN&((!black)<<1);
	currently_pressed_buttons |= BUTTON_SET&((!blue) <<2);
	currently_pressed_buttons |= BUTTON_BACK&((!green)<<3);
}

void main(void)
{
	bool update_display = true;

	unsigned char temp_sensor_config = 0x00;

	unsigned char currently_picked_mode = MODE_CONFIGURE_TEMP_HIGH;

	float current_temp = 0, last_temp = 0;
	
	// Wait a tic for stuff to boot
	delay(100); 

	// Display setup
	write_display_command(ENABLE_DISPLAY_OSCILLATOR);
	write_display_command(ENABLE_DISPLAY);
	write_display_command(SET_DISPLAY_BRIGHTNESS|HALF_BRIGHTNESS);

	// Temp sensor setup
	temp_sensor_config |= TEMP_SENSOR_OUTPUT_HIGH;
	temp_sensor_config |= TEMP_SENSOR_ONE_SHOT_CONVERSION;

	write_temp_sensor_config(temp_sensor_config);

	// We need a loop in main, otherwise we do not have deterministic looping
	// behavior.  The program is re-executed once the instruction pointer has
	// run to the "end".  In other words, all global vars will be reset, and
	// the program begins execution as though it were being loaded and run
	// for the first time again.
	while (true)
	{
		read_buttons();
		switch(current_user_mode)
		{
		case MODE_DISPLAY_TEMPERATURE:
			if (currently_pressed_buttons & BUTTON_SET) 
			{
				current_user_mode = MODE_PICK_SETTING;
				continue;
			}
			current_temp = read_temp_sensor();
			if (last_temp != current_temp)
			{
				update_displayed_temperature(current_temp);
				last_temp = current_temp;
				update_display = true;
			}
			break;
		case MODE_CONFIGURE_TEMP_HIGH    :
			if (currently_pressed_buttons & BUTTON_SET)
			{
				current_user_mode = MODE_DISPLAY_TEMPERATURE;
			} 
			else if (currently_pressed_buttons & BUTTON_BACK)
			{
				current_user_mode = MODE_PICK_SETTING;
			}
			update_displayed_temperature(user_setting_temp_high_threshold);
			update_display = true;
			break;
		case MODE_CONFIGURE_TEMP_LOW     :
			if (currently_pressed_buttons & BUTTON_SET)
			{
				current_user_mode = MODE_DISPLAY_TEMPERATURE;
			} 
			else if (currently_pressed_buttons & BUTTON_BACK)
			{
				current_user_mode = MODE_PICK_SETTING;
			}
			update_displayed_temperature(user_setting_temp_low_threshold);
			update_display = true;
			break;
		case MODE_CONFIGURE_TEMP_UNIT    :
			break;
		case MODE_CONFIGURE_TEMP_ROUNDING:
			break;
		case MODE_CONFIGURE_BRIGHTNESS   :
			break;
		case MODE_PICK_SETTING:
			if (BUTTON_DOWN & currently_pressed_buttons & debounced_buttons)
			{
				--currently_picked_mode;
				if (currently_picked_mode < MODE_CONFIGURE_TEMP_HIGH) 
				{
					currently_picked_mode = MODE_CONFIGURE_BRIGHTNESS;
					updated_displayed_setting_selection(currently_picked_mode);
				}
				debounced_buttons |= BUTTON_DOWN;
			} else {
				debounced_buttons &= (!BUTTON_DOWN);
			}
			if (BUTTON_UP & currently_pressed_buttons & debounced_buttons)
			{
				++currently_picked_mode;
				if (currently_picked_mode > MODE_CONFIGURE_BRIGHTNESS) 
				{
					currently_picked_mode = MODE_CONFIGURE_TEMP_HIGH;
					updated_displayed_setting_selection(currently_picked_mode);
				}
				debounced_buttons |= BUTTON_UP;
			} else {
				debounced_buttons &= (!BUTTON_UP);
			}
			if (currently_pressed_buttons & BUTTON_SET & debounced_buttons)
			{
				current_user_mode = currently_picked_mode;
			} 
			else if (currently_pressed_buttons & BUTTON_BACK & debounced_buttons)
			{
				current_user_mode = MODE_DISPLAY_TEMPERATURE;
			}

			update_display = true;
			break;
		default: 
			current_user_mode = MODE_DISPLAY_TEMPERATURE; 
			update_display = true; 
			break;
		}

		if (update_display) 
		{
			write_to_display();
			update_display = false;
		}
	}
}

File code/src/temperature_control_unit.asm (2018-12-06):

;--------------------------------------------------------
; File Created by SDCC : free open source ANSI-C Compiler
; Version 3.5.0 #9253 (Apr  3 2018) (Linux)
; This file was generated Wed Dec  5 16:43:04 2018
;--------------------------------------------------------
	.module temperature_control_unit
	.optsdcc -mmcs51 --model-small
	
;--------------------------------------------------------
; Public variables in this module
;--------------------------------------------------------
	.globl _i2c_sda_write_PARM_2
	.globl _main
	.globl _read_buttons
	.globl _updated_displayed_setting_selection
	.globl _update_displayed_temperature
	.globl _write_to_display
	.globl _modff
	.globl _CY
	.globl _AC
	.globl _F0
	.globl _RS1
	.globl _RS0
	.globl _OV
	.globl _F1
	.globl _P
	.globl _PS
	.globl _PT1
	.globl _PX1
	.globl _PT0
	.globl _PX0
	.globl _RD
	.globl _WR
	.globl _T1
	.globl _T0
	.globl _INT1
	.globl _INT0
	.globl _TXD
	.globl _RXD
	.globl _P3_7
	.globl _P3_6
	.globl _P3_5
	.globl _P3_4
	.globl _P3_3
	.globl _P3_2
	.globl _P3_1
	.globl _P3_0
	.globl _EA
	.globl _ES
	.globl _ET1
	.globl _EX1
	.globl _ET0
	.globl _EX0
	.globl _P2_7
	.globl _P2_6
	.globl _P2_5
	.globl _P2_4
	.globl _P2_3
	.globl _P2_2
	.globl _P2_1
	.globl _P2_0
	.globl _SM0
	.globl _SM1
	.globl _SM2
	.globl _REN
	.globl _TB8
	.globl _RB8
	.globl _TI
	.globl _RI
	.globl _P1_7
	.globl _P1_6
	.globl _P1_5
	.globl _P1_4
	.globl _P1_3
	.globl _P1_2
	.globl _P1_1
	.globl _P1_0
	.globl _TF1
	.globl _TR1
	.globl _TF0
	.globl _TR0
	.globl _IE1
	.globl _IT1
	.globl _IE0
	.globl _IT0
	.globl _P0_7
	.globl _P0_6
	.globl _P0_5
	.globl _P0_4
	.globl _P0_3
	.globl _P0_2
	.globl _P0_1
	.globl _P0_0
	.globl _B
	.globl _ACC
	.globl _PSW
	.globl _IP
	.globl _P3
	.globl _IE
	.globl _P2
	.globl _SBUF
	.globl _SCON
	.globl _P1
	.globl _TH1
	.globl _TH0
	.globl _TL1
	.globl _TL0
	.globl _TMOD
	.globl _TCON
	.globl _PCON
	.globl _DPH
	.globl _DPL
	.globl _SP
	.globl _P0
	.globl _i2c_send_byte_PARM_2
	.globl _i2c_scl_write_PARM_2
	.globl _user_setting_temp_low_threshold
	.globl _user_setting_temp_high_threshold
	.globl _current_user_mode
	.globl _display_brightness
	.globl _debounced_buttons
	.globl _currently_pressed_buttons
	.globl _display_buffer
	.globl _number_table
	.globl _delay
	.globl _i2c_delay
	.globl _i2c_sda_write
	.globl _i2c_sda_read
	.globl _i2c_scl_write
	.globl _i2c_start
	.globl _i2c_stop
	.globl _i2c_send_byte
	.globl _i2c_read_byte
	.globl _read_temp_sensor
	.globl _clear_display_buffer
	.globl _write_display_command
	.globl _write_temp_sensor_config
	.globl _write_temp_sensor_command
;--------------------------------------------------------
; special function registers
;--------------------------------------------------------
	.area RSEG    (ABS,DATA)
	.org 0x0000
_P0	=	0x0080
_SP	=	0x0081
_DPL	=	0x0082
_DPH	=	0x0083
_PCON	=	0x0087
_TCON	=	0x0088
_TMOD	=	0x0089
_TL0	=	0x008a
_TL1	=	0x008b
_TH0	=	0x008c
_TH1	=	0x008d
_P1	=	0x0090
_SCON	=	0x0098
_SBUF	=	0x0099
_P2	=	0x00a0
_IE	=	0x00a8
_P3	=	0x00b0
_IP	=	0x00b8
_PSW	=	0x00d0
_ACC	=	0x00e0
_B	=	0x00f0
;--------------------------------------------------------
; special function bits
;--------------------------------------------------------
	.area RSEG    (ABS,DATA)
	.org 0x0000
_P0_0	=	0x0080
_P0_1	=	0x0081
_P0_2	=	0x0082
_P0_3	=	0x0083
_P0_4	=	0x0084
_P0_5	=	0x0085
_P0_6	=	0x0086
_P0_7	=	0x0087
_IT0	=	0x0088
_IE0	=	0x0089
_IT1	=	0x008a
_IE1	=	0x008b
_TR0	=	0x008c
_TF0	=	0x008d
_TR1	=	0x008e
_TF1	=	0x008f
_P1_0	=	0x0090
_P1_1	=	0x0091
_P1_2	=	0x0092
_P1_3	=	0x0093
_P1_4	=	0x0094
_P1_5	=	0x0095
_P1_6	=	0x0096
_P1_7	=	0x0097
_RI	=	0x0098
_TI	=	0x0099
_RB8	=	0x009a
_TB8	=	0x009b
_REN	=	0x009c
_SM2	=	0x009d
_SM1	=	0x009e
_SM0	=	0x009f
_P2_0	=	0x00a0
_P2_1	=	0x00a1
_P2_2	=	0x00a2
_P2_3	=	0x00a3
_P2_4	=	0x00a4
_P2_5	=	0x00a5
_P2_6	=	0x00a6
_P2_7	=	0x00a7
_EX0	=	0x00a8
_ET0	=	0x00a9
_EX1	=	0x00aa
_ET1	=	0x00ab
_ES	=	0x00ac
_EA	=	0x00af
_P3_0	=	0x00b0
_P3_1	=	0x00b1
_P3_2	=	0x00b2
_P3_3	=	0x00b3
_P3_4	=	0x00b4
_P3_5	=	0x00b5
_P3_6	=	0x00b6
_P3_7	=	0x00b7
_RXD	=	0x00b0
_TXD	=	0x00b1
_INT0	=	0x00b2
_INT1	=	0x00b3
_T0	=	0x00b4
_T1	=	0x00b5
_WR	=	0x00b6
_RD	=	0x00b7
_PX0	=	0x00b8
_PT0	=	0x00b9
_PX1	=	0x00ba
_PT1	=	0x00bb
_PS	=	0x00bc
_P	=	0x00d0
_F1	=	0x00d1
_OV	=	0x00d2
_RS0	=	0x00d3
_RS1	=	0x00d4
_F0	=	0x00d5
_AC	=	0x00d6
_CY	=	0x00d7
;--------------------------------------------------------
; overlayable register banks
;--------------------------------------------------------
	.area REG_BANK_0	(REL,OVR,DATA)
	.ds 8
;--------------------------------------------------------
; internal ram data
;--------------------------------------------------------
	.area DSEG    (DATA)
_number_table::
	.ds 16
_display_buffer::
	.ds 10
_currently_pressed_buttons::
	.ds 1
_debounced_buttons::
	.ds 1
_display_brightness::
	.ds 1
_current_user_mode::
	.ds 1
_user_setting_temp_high_threshold::
	.ds 2
_user_setting_temp_low_threshold::
	.ds 2
_i2c_scl_write_PARM_2:
	.ds 1
_i2c_send_byte_PARM_2:
	.ds 1
_read_temp_sensor_slope_1_63:
	.ds 4
_read_temp_sensor_count_remaining_1_63:
	.ds 4
_update_displayed_temperature_temperature_1_76:
	.ds 4
_update_displayed_temperature_temp_fraction_part_1_77:
	.ds 4
_update_displayed_temperature_temp_integer_part_1_77:
	.ds 4
_update_displayed_temperature_sloc0_1_0:
	.ds 2
_update_displayed_temperature_sloc1_1_0:
	.ds 1
_update_displayed_temperature_sloc2_1_0:
	.ds 1
_main_last_temp_1_89:
	.ds 4
;--------------------------------------------------------
; overlayable items in internal ram 
;--------------------------------------------------------
	.area	OSEG    (OVR,DATA)
_delay_min_clock_cycles_to_wait_1_37:
	.ds 4
	.area	OSEG    (OVR,DATA)
	.area	OSEG    (OVR,DATA)
_i2c_sda_write_PARM_2:
	.ds 1
	.area	OSEG    (OVR,DATA)
	.area	OSEG    (OVR,DATA)
	.area	OSEG    (OVR,DATA)
;--------------------------------------------------------
; Stack segment in internal ram 
;--------------------------------------------------------
	.area	SSEG
__start__stack:
	.ds	1
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

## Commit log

2018-10-25 Add additional directories for documentation Add log files to .gitignore Include list of ordered parts (experimental or otherwise)
    [lutterman_parts_ordered_Oct-24-2018.csv]
2018-10-25 Add additional documentation, schematics, data sheets; Update README
    [preliminary.sch]
2018-10-25 Add small image for prelim schematic
2018-11-01 Add version 5 of TCU schematic and board layout
    [Schem_5_breakout.brd, Schem_5_breakout.sch]
2018-11-01 Edited component name and value locations
    [Schem_5_breakout.brd]
2018-11-01 uploaded tcu board V2 image
2018-11-01 chagned file names
    [Schem_5_breakout_Grp_16.brd]
2018-11-02 Added bypass caps and test points
    [ECE411_G16_V5.brd, ECE411_G16_V5.sch, ECE411_G16_V6.brd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]
2018-11-03 added user interface schematic and board, added some images
    [User_Interface.brd, User_Interface.sch]
2018-11-07 Post design review version 7
    [ECE411_G16_V7.brd, ECE411_G16_V7.sch]
2018-11-07 tidying up
    [ECE411_G16_V5.brd, ECE411_G16_V5.sch, ECE411_G16_V6.brd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]
2018-11-13 Added V8 shcematic and board images
2018-11-13 Added .schem and .brd for V8
    Added test jumpers at +12 V
    Added Jumpers for fan and light
    Added additional I/O pins
    Added bypass cap for DS1621
    Moved power supply
    General redesign
    [ECE411_G16_V8.brd, ECE411_G16_V8.sch]
2018-11-14 Added "final" versions of schematic and board
    [ECE411_G16_V10.brd, ECE411_G16_V10.sch]
2018-11-15 THE final versions of schematic and PCB
    [ECE411_G16_V11.brd, ECE411_G16_V11.sch]
2018-11-23 Added test plan 1
    [ECE411_TP1_G16.xlsx]
2018-11-29 Add data sheets for the 7-segment LED display, its controller, and the USB ASP
2018-11-29 Add schematic for 7-seg display with backpack
2018-11-29 Add (incomplete) test plan for checking that output of DS1621 matches output of AT89S52 to LED display
    [ECE411_TP2_G16.xlsx]
2018-11-29 Added test plan 2
    [ECE411_TP2_G16.xlsx]
2018-12-03 Create ECE411_TP3_G16 (2).xlsx
    File conflict. Renamed Nathan's test plan 2 test plan 3
    [ECE411_TP3_G16 (2).xlsx]
2018-12-04 Add 8051 hardware manual as well as temperature sensor's I2C waveforms
2018-12-04 Add code for gathering and displaying temperature from sensor to 7 seg display
2018-12-06 Added relay/button testing code
2018-12-06 the end
    [ECE411_G16_V12.sch, User_Interface_5.brd, User_Interface_5.sch]

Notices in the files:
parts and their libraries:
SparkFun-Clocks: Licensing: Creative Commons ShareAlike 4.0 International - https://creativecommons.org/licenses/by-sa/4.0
